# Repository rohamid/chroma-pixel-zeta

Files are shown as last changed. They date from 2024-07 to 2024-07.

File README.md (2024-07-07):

# TODO #
* Using IS42S16160 which is actually 32MB SDRAM, there must be 13 bit address (A0-A12). But I only populated 12-bit (A0-A11). Fix This
* Move the LCD FPC 40P slightly inside the PCB in order to match the actual LCD bend.
* Add VBUS control to the USB C in order to use USB Host capability
* I forgot to route 5V to 4P the JST-XH connector
* Rotate the ST-Link connector 180 degree to match the actual ST-Link connector bend

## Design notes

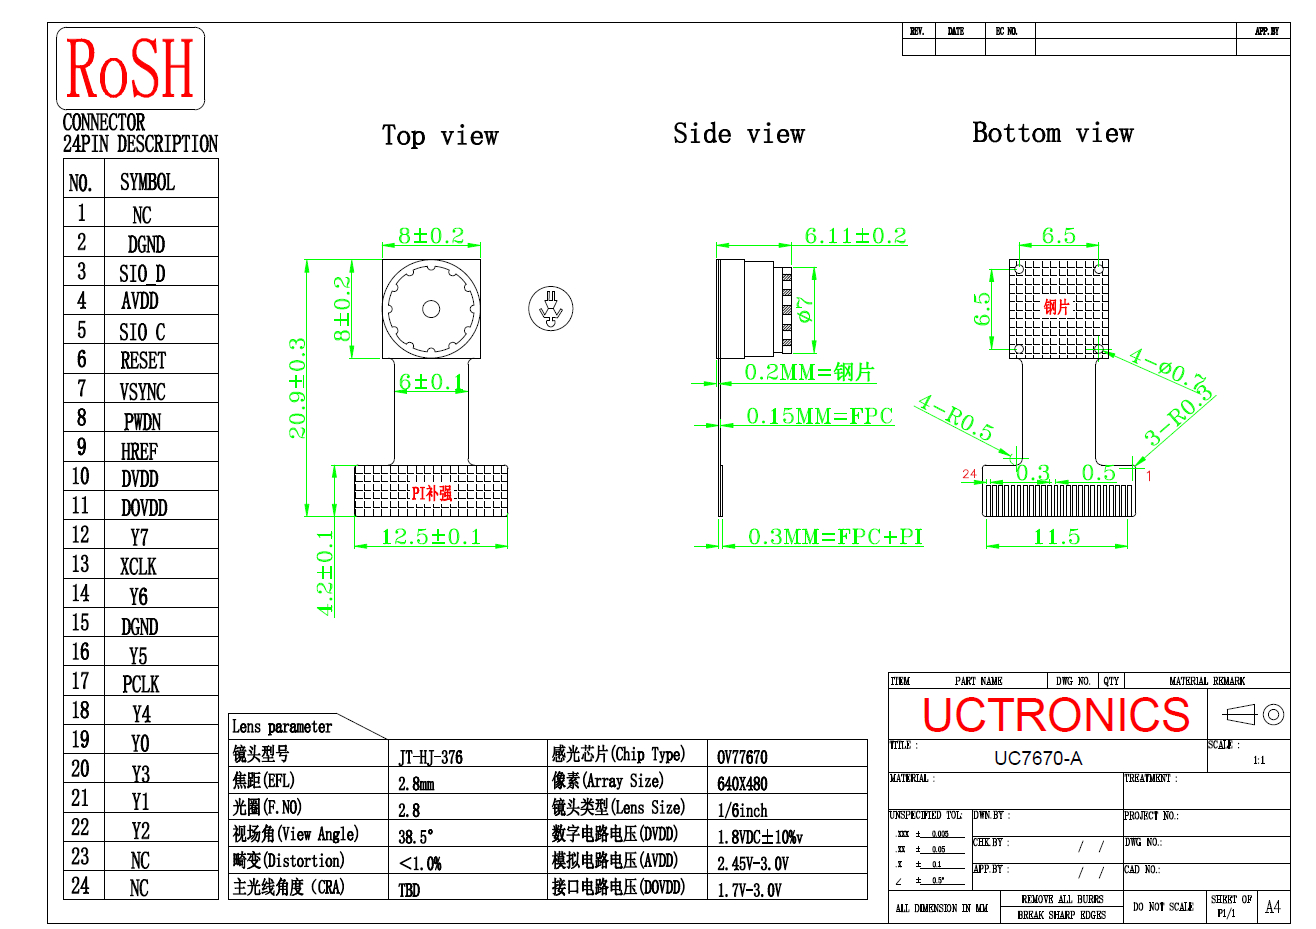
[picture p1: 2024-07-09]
doc/ezgif-5-22a7d3f66d.jpg

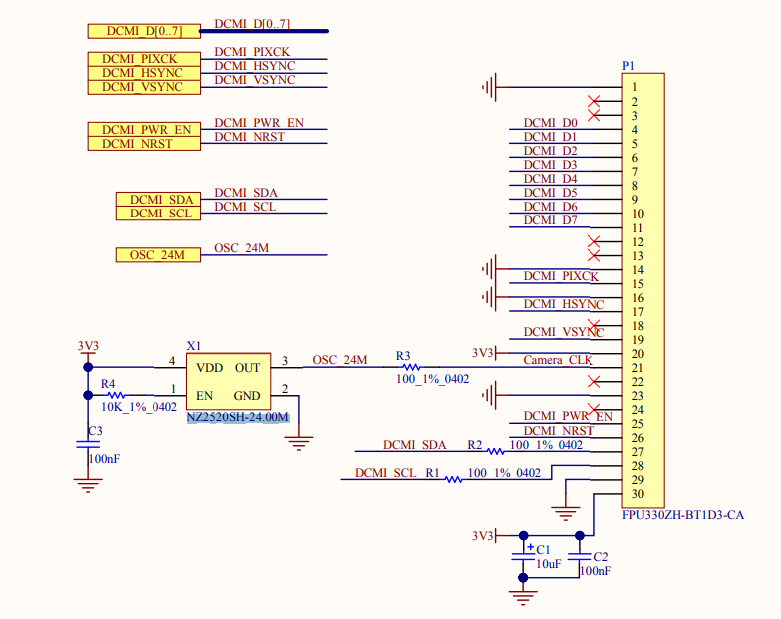
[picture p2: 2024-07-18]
camera-stm32.png

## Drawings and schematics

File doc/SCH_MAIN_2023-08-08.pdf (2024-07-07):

VDD 72 PB12 73 PB13 74 PB14 75 PB15 76 PD8 77 PD9 78 PD10 79 PD11 80 PD12 81 PD13 82 VSS 83 VDD 84 PD14 85 PD15 86 PG2 87 PG3 88 PG4 89 PG5 90 PG6 91 PG7 92 PG8 93 VSS 94 VDD33USB 95 PC6 96 PC7 97 PC8 98 PC9 99 PA8 100 PA9 101 PA10 102 PA11 103 PA12 104 PA13 105 VCAP 106 VSS 107 VDD 108 PA14 109 PA15 110 PC10 111 PC11 112 PC12 113 PD0 114 PD1 115 PD2 116 PD3 117 PD4 118 PD5 119 VSS 120 VDD 121 PD6 122 PD7 123 PG9 124 PG10 125 PG11 126 PG12 127 PG13 128 PG14 129 VSS 130 VDD 131 PG15 132 PB3 133 PB4 134 PB5 135 PB6 136 PB7 137 BOOT0 138 PB8 139 PB9 140 PE0 141 PE1 142 PDR_ON 143 VDD 144

# SDRAM

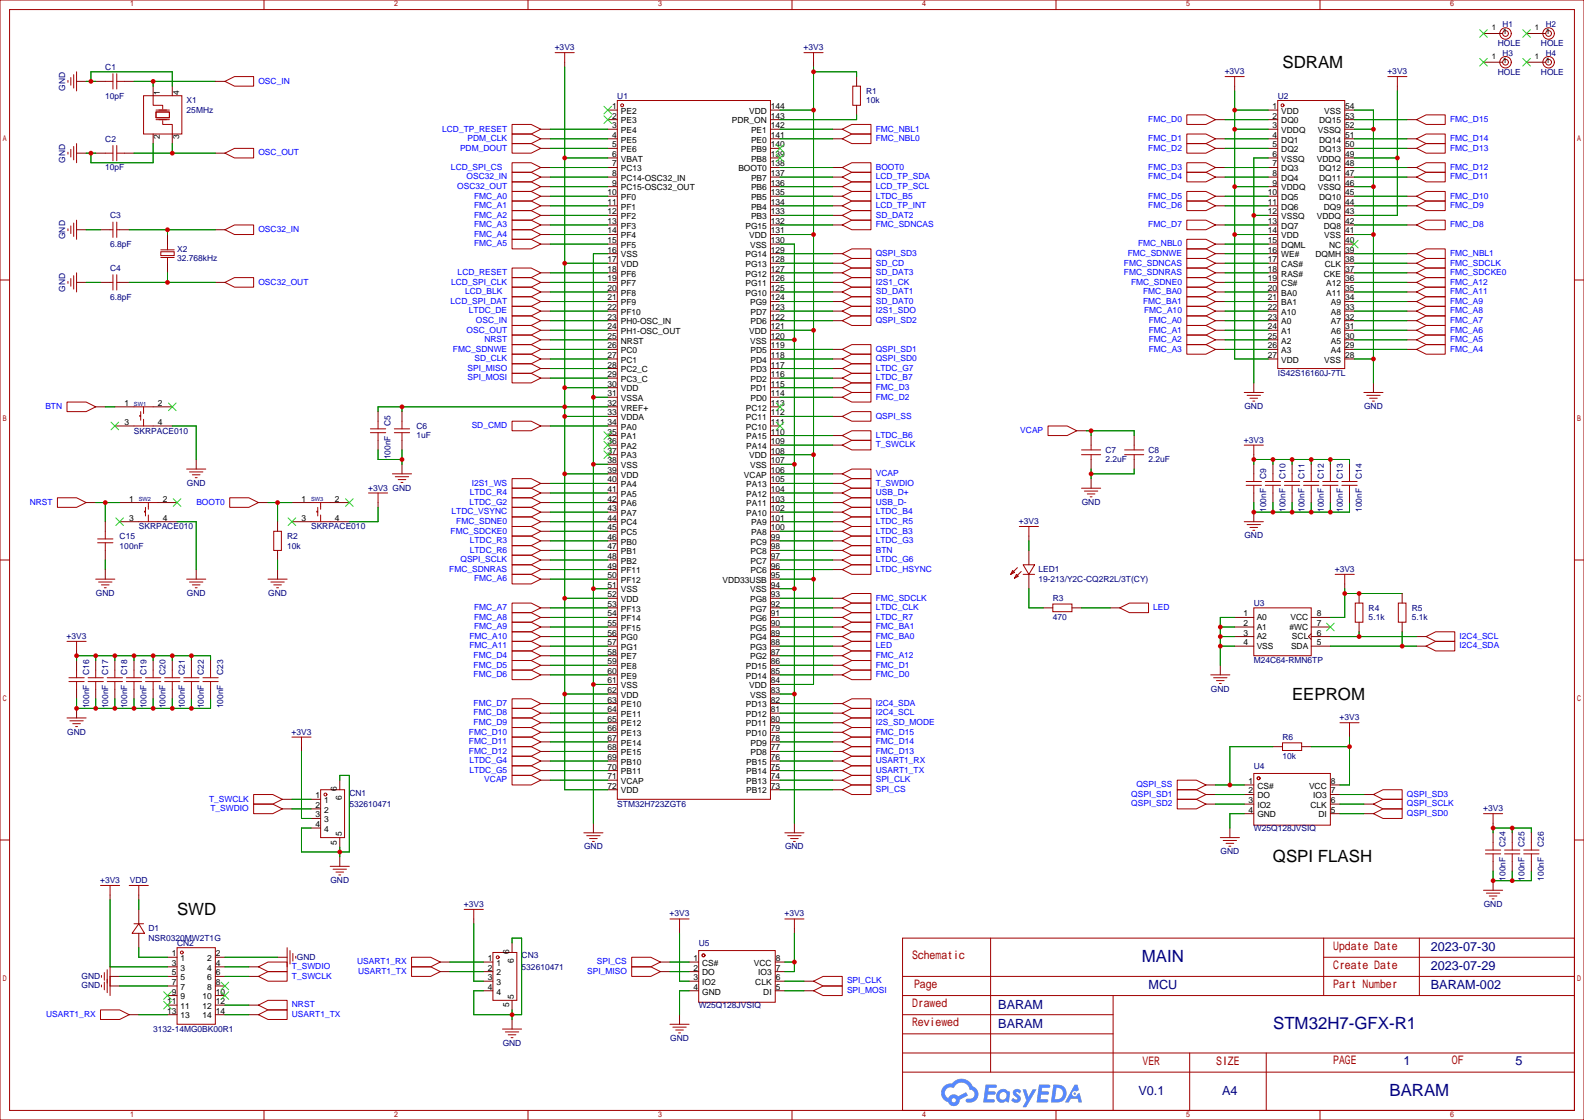
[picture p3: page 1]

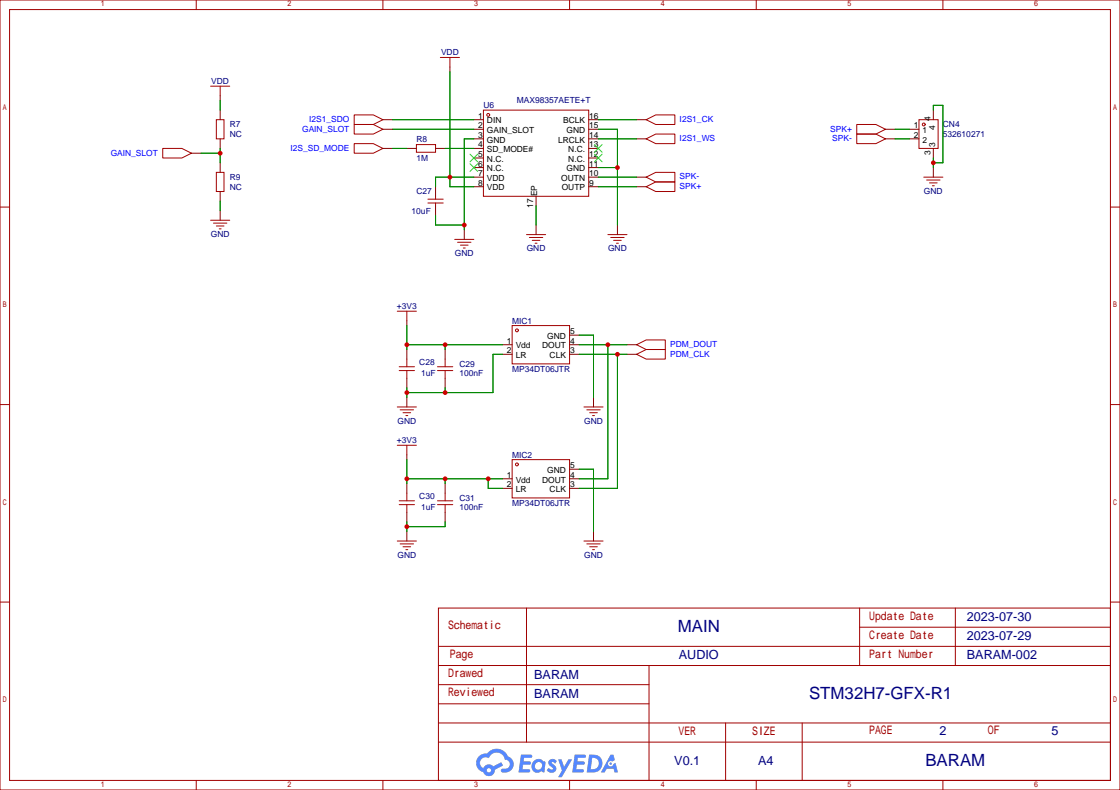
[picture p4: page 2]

OUTN 10 GND 11 N.C. 12 N.C. 13 LRCLK 14 GND 15 BCLK 16

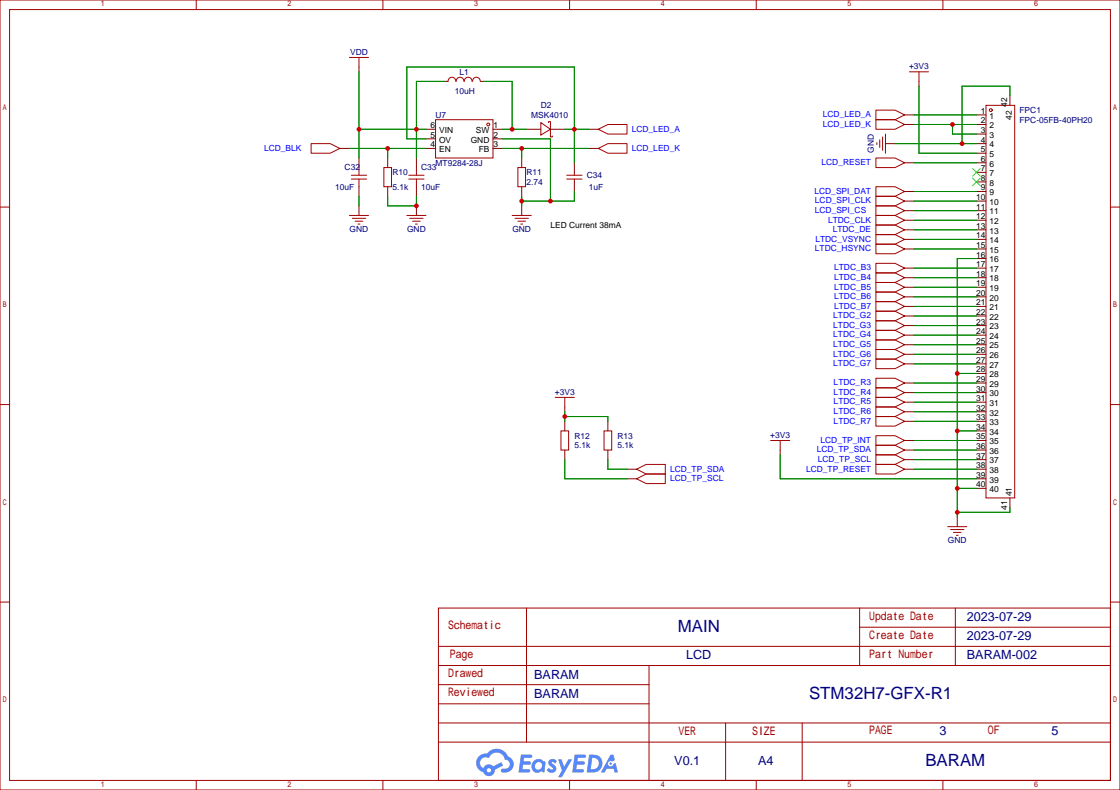
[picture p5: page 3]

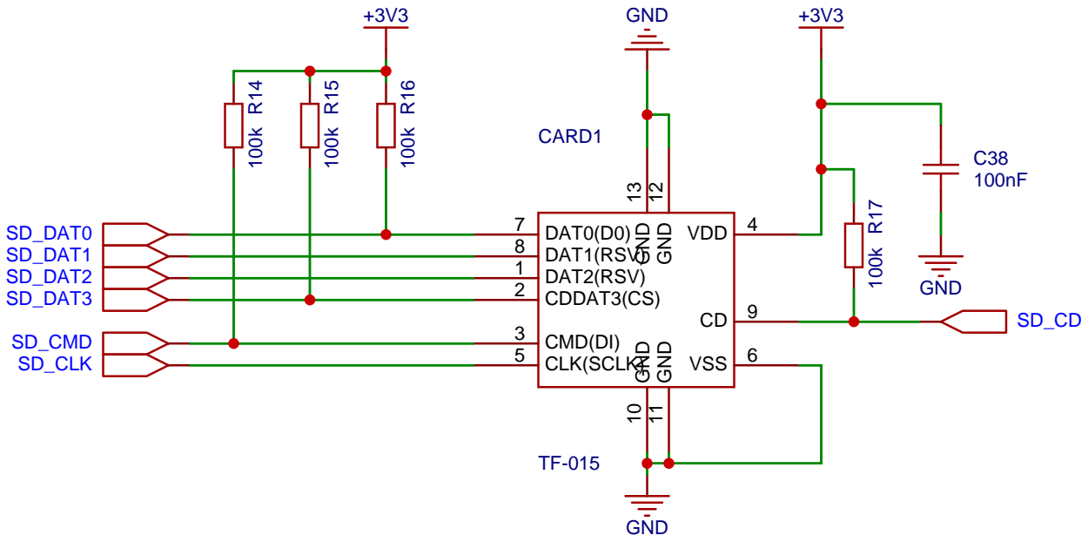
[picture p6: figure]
DAT2(RSV) 1 CDDAT3(CS) 2; CMD(DI) 3; VDD 4; CLK(SCLK) 5; VSS 6; DAT0(D0) 7; DAT1(RSV) 8; GND ¹³ GND 10; GND 11 GND 12; CARD1; GND; SD_DAT0 SD_DAT1 SD_DAT2 SD_DAT3; SD_CMD SD_CLK

Reviewed

Drawed

Create Date
Part Number

Schematic

Update Date

Page

## BARAM BARAM

# STM32H7-GFX-R1

2023-07-30

## 2023-07-29 MAIN

## BARAM-002

## SDCARD

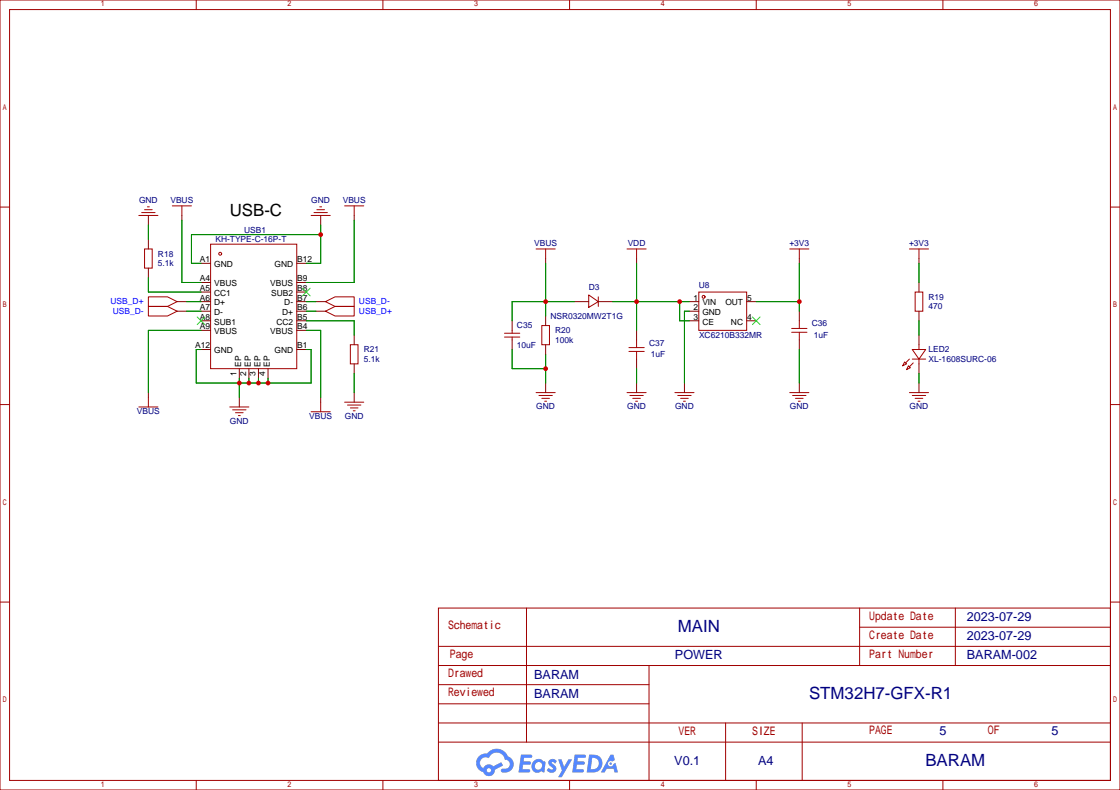
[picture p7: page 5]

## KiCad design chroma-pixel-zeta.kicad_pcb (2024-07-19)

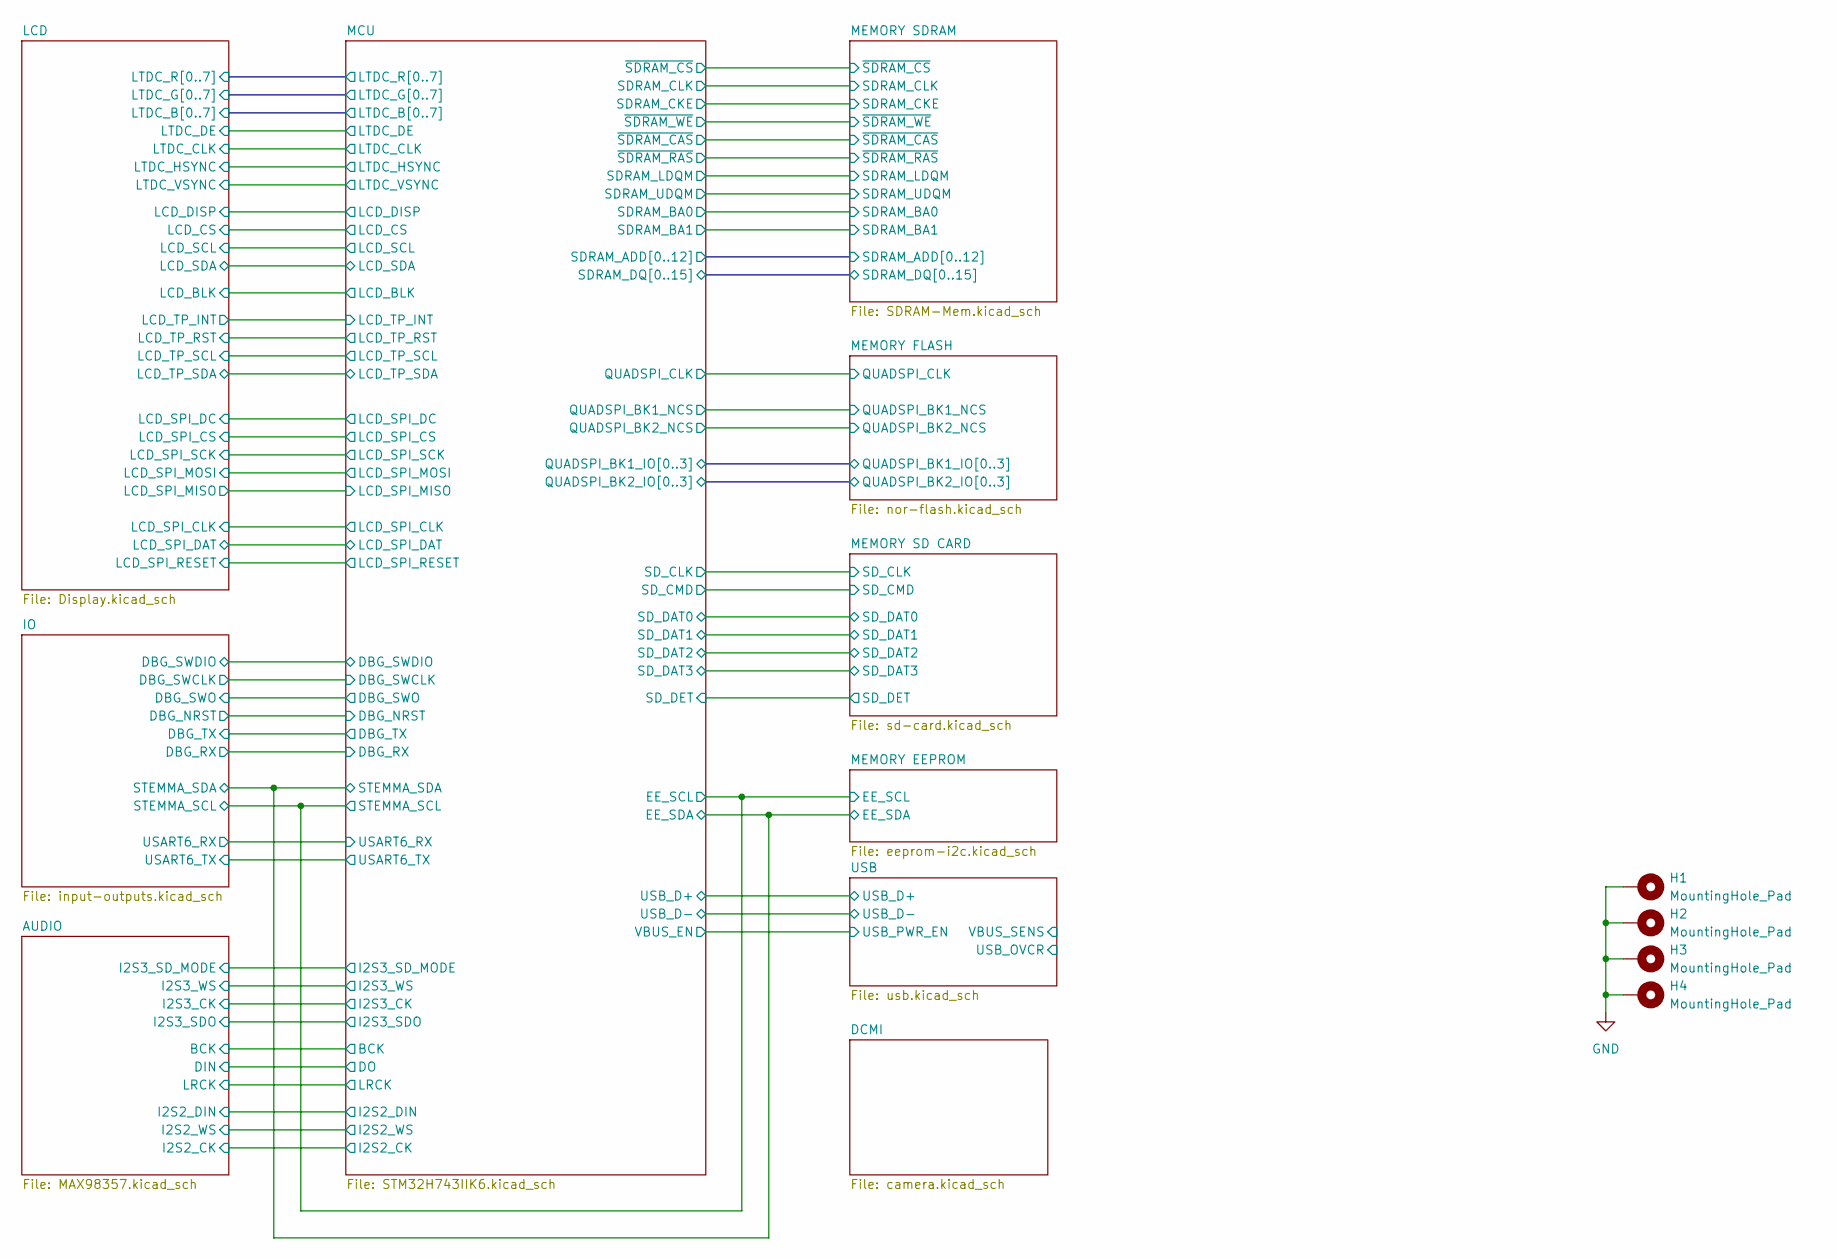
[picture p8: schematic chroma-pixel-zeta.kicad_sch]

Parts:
H1, H2, H3, H4: MountingHole_Pad; MountingHole_3.2mm_M3_Pad_Via

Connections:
GND: H1.1, H2.1, H3.1, H4.1; also elsewhere on the board

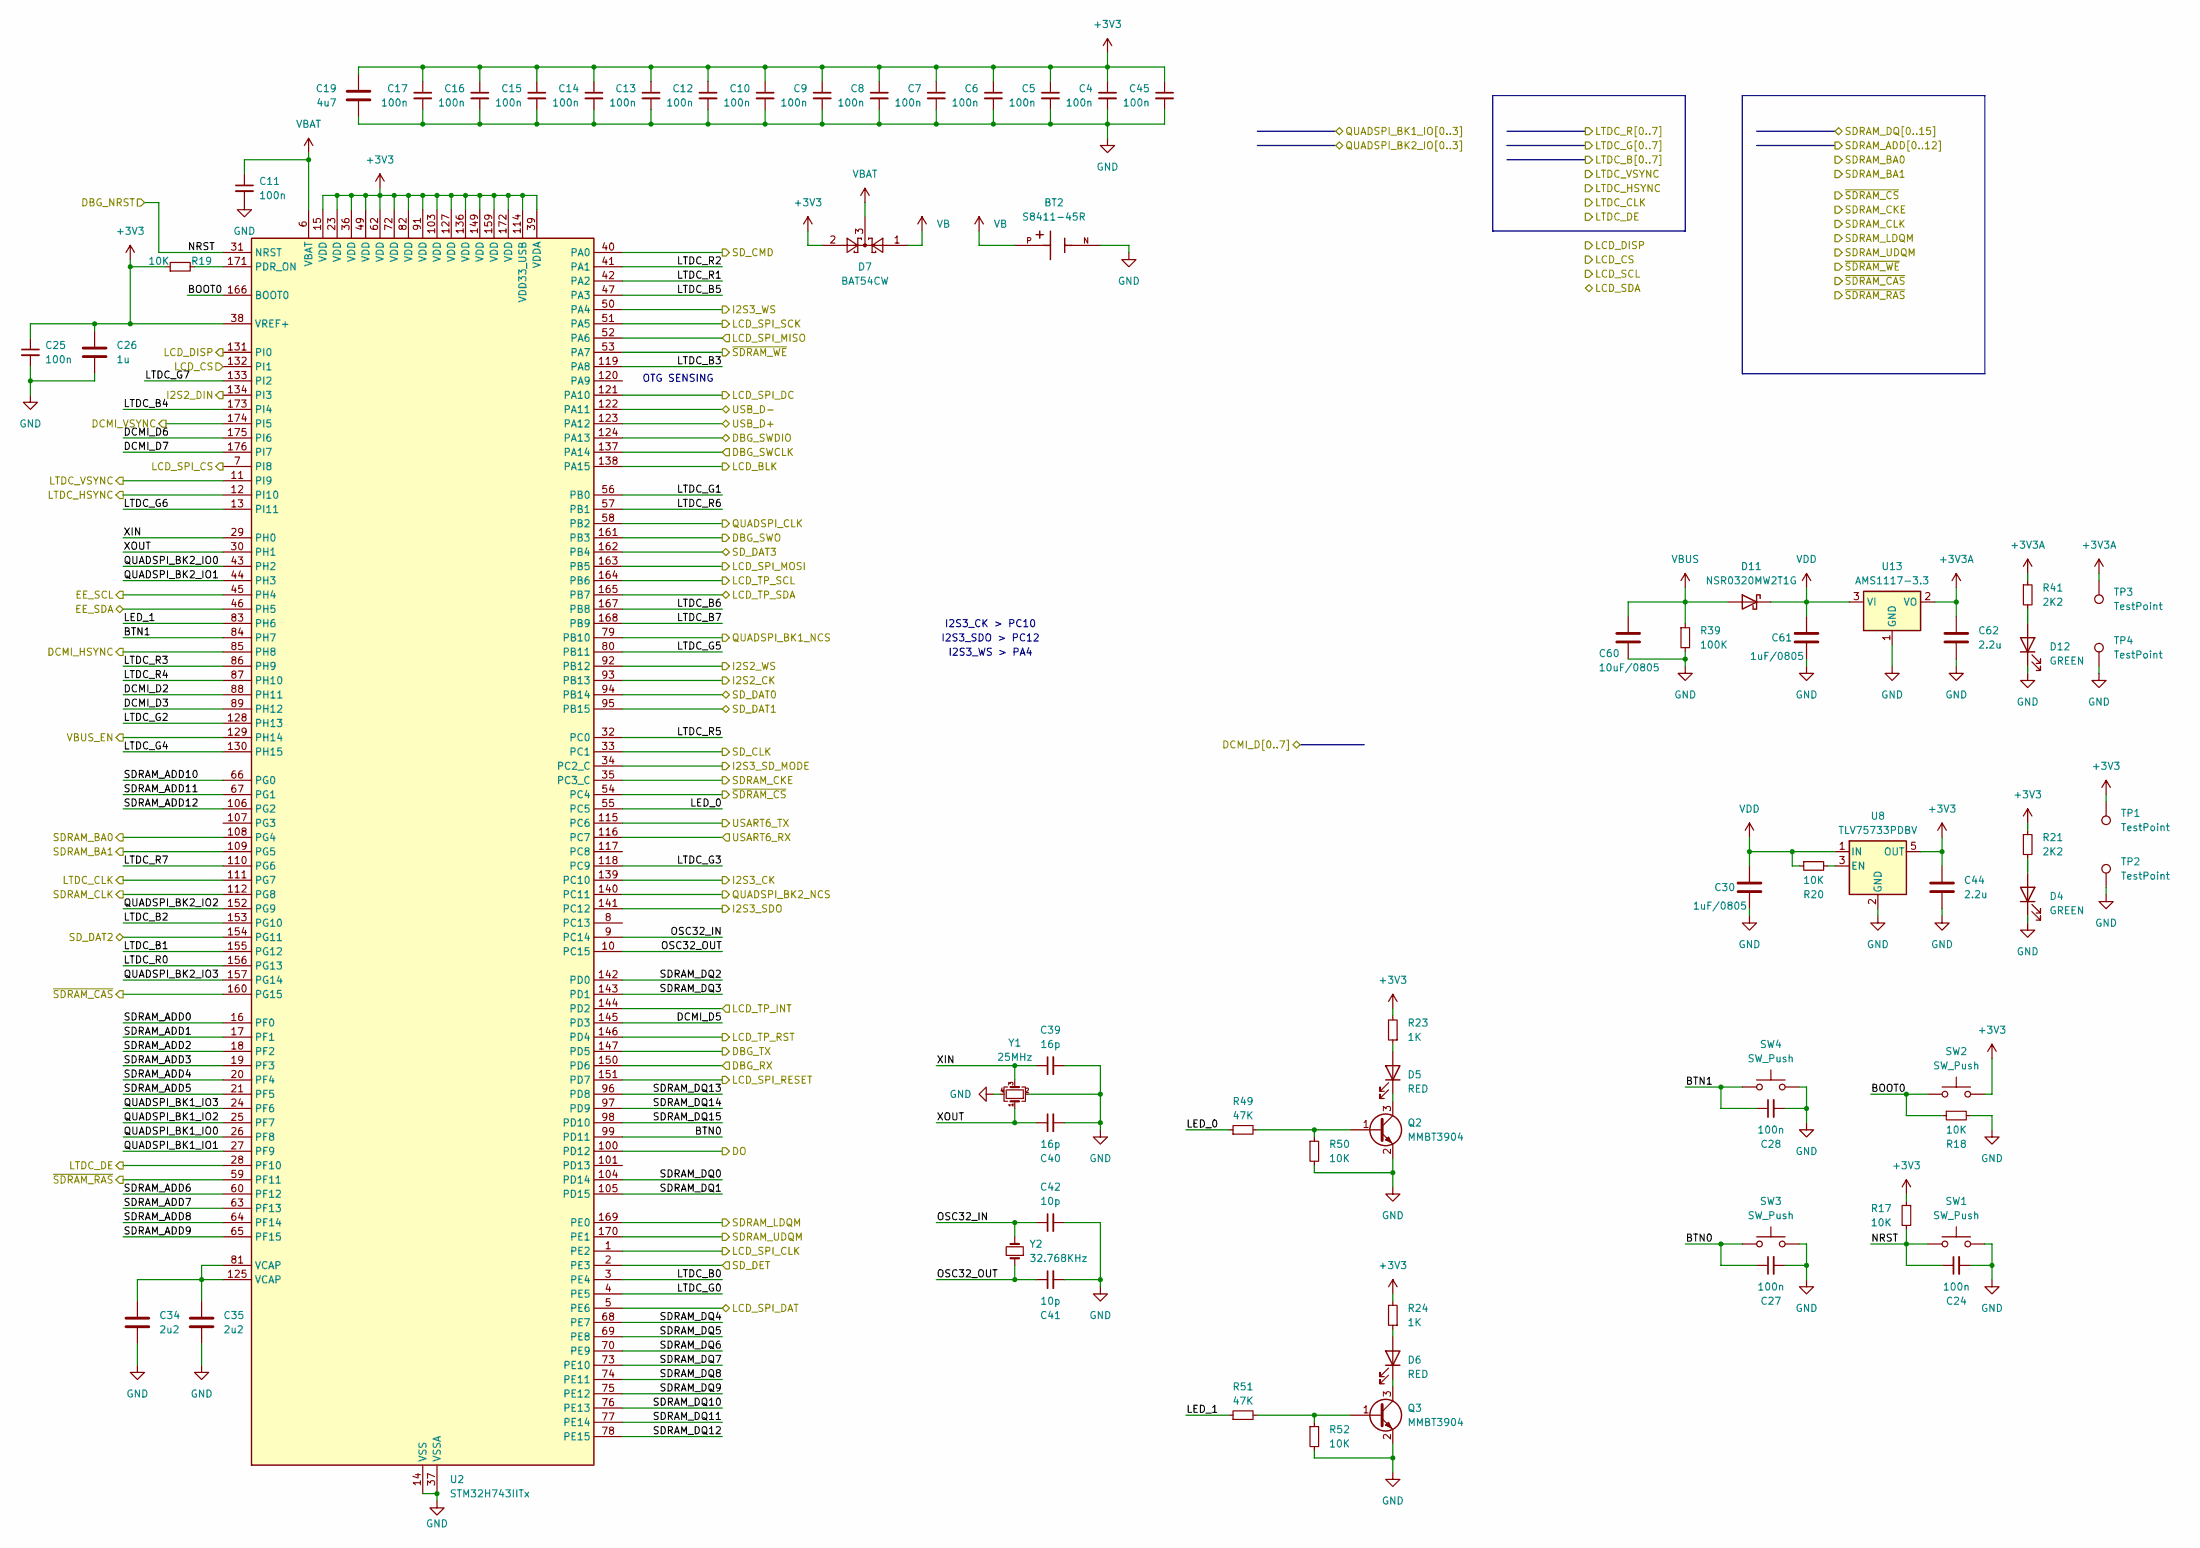
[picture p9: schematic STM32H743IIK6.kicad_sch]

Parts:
BT2: S8411-45R; CR1220-Batt-conn-S8411-45R; JLCPCB Part # C964729
C4, C5, C6, C7, C8, C9, C10, C11, C12, C13, C14, C15, C16, C17, C24, C25, C27, C28, C45: 100n; C_0402_1005Metric; JLCPCB Part # C307331
C19: 4u7; C_0603_1608Metric; JLCPCB Part # C19666
C26: 1u; C_0603_1608Metric; JLCPCB Part # C15849
C30, C61: 1uF/0805; C_0805_2012Metric; JLCPCB Part # C28323
C34, C35: 2u2; C_0603_1608Metric; JLCPCB Part # C23630
C39, C40: 16p; C_0402_1005Metric; JLCPCB Part # C77590
C41, C42: 10p; C_0402_1005Metric; JLCPCB Part # C32949
C44, C62: 2.2u; C_0805_2012Metric; JLCPCB Part # C377773
C60: 10uF/0805; C_0805_2012Metric; JLCPCB Part # C440198
D4, D12: GREEN; LED_0805_2012Metric; JLCPCB Part # C2297
D5, D6: RED; LED_0805_2012Metric; JLCPCB Part # C84256
D7: BAT54CW; SOT-23; JLCPCB Part # C37704
D11: NSR0320MW2T1G; D_SOD-323; JLCPCB Part # C48192
Q2, Q3: MMBT3904; SOT-23; JLCPCB Part # C20526
R17, R18, R19, R20, R50, R52: 10K; R_0402_1005Metric; JLCPCB Part # C25744
R21, R41: 2K2; R_0402_1005Metric; JLCPCB Part # C25879
R23, R24: 1K; R_0402_1005Metric; JLCPCB Part # C11702
R39: 100K; R_0402_1005Metric; JLCPCB Part # C60491
R49, R51: 47K; R_0402_1005Metric; JLCPCB Part # C25741
SW1, SW2, SW3, SW4: SW_Push; SW_SPST_PTS810; JLCPCB Part # C127488
TP1, TP2, TP3, TP4: TestPoint; TestPoint_Pad_D1.5mm
U2: STM32H743IITx; LQFP-176_24x24mm_P0.5mm; JLCPCB Part # C89597
U8: TLV75733PDBV; SOT-23-5; JLCPCB Part # C485517
U13: AMS1117-3.3; SOT-223-3_TabPin2; JLCPCB Part # C6186
Y1: 25MHz; Crystal_SMD_2520-4Pin_2.5x2.0mm; JLCPCB Part # C255954
Y2: 32.768KHz; Crystal_SMD_2012-2Pin_2.0x1.2mm; JLCPCB Part # C99009

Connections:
+3V3: C4.1, C5.1, C6.1, C7.1, C8.1, C9.1, C10.1, C12.1, C13.1, C14.1, C15.1, C16.1, C17.1, C19.1, C25.1, C26.1, C44.1, C45.1, D7.2, R17.1, R19.1, R21.1, R23.2, R24.2, SW2.2, TP1.1, U2.15 (VDD), U2.23 (VDD), U2.36 (VDD), U2.38 (VREF+), U2.39 (VDDA), U2.49 (VDD), U2.62 (VDD), U2.72 (VDD), U2.82 (VDD), U2.91 (VDD), U2.103 (VDD), U2.114 (VDD33_USB), U2.127 (VDD), U2.136 (VDD), U2.149 (VDD), U2.159 (VDD), U2.172 (VDD), U8.5 (OUT); also elsewhere on the board
+3V3A: C62.1, R41.1, TP3.1, U13.2 (VO); also elsewhere on the board
/AUDIO/I2S2_CK: U2.93 (PB13); also elsewhere on the board
/AUDIO/I2S2_DIN: U2.134 (PI3); also elsewhere on the board
/AUDIO/I2S2_WS: U2.92 (PB12); also elsewhere on the board
/AUDIO/I2S3_CK: U2.139 (PC10); also elsewhere on the board
/AUDIO/I2S3_SDO: U2.141 (PC12); also elsewhere on the board
/AUDIO/I2S3_SD_MODE: U2.34 (PC2_C); also elsewhere on the board
/AUDIO/I2S3_WS: U2.50 (PA4); also elsewhere on the board
/IO/DBG_RX: U2.150 (PD6); also elsewhere on the board
/IO/DBG_SWCLK: U2.137 (PA14); also elsewhere on the board
/IO/DBG_SWDIO: U2.124 (PA13); also elsewhere on the board
/IO/DBG_SWO: U2.161 (PB3); also elsewhere on the board
/IO/DBG_TX: U2.147 (PD5); also elsewhere on the board
/IO/STEMMA_SCL: U2.45 (PH4); also elsewhere on the board
/IO/STEMMA_SDA: U2.46 (PH5); also elsewhere on the board
/IO/USART6_RX: U2.116 (PC7); also elsewhere on the board
/IO/USART6_TX: U2.115 (PC6); also elsewhere on the board
/LCD/LCD_BLK: U2.138 (PA15); also elsewhere on the board
/LCD/LCD_CS: U2.132 (PI1); also elsewhere on the board
/LCD/LCD_DC: U2.121 (PA10); also elsewhere on the board
/LCD/LCD_DISP: U2.131 (PI0); also elsewhere on the board
/LCD/LCD_SCK: U2.51 (PA5); also elsewhere on the board
/LCD/LCD_SDI(MOSI): U2.163 (PB5); also elsewhere on the board
/LCD/LCD_SDO(MISO): U2.52 (PA6); also elsewhere on the board
/LCD/LCD_SPI_CLK: U2.1 (PE2); also elsewhere on the board
/LCD/LCD_SPI_CS: U2.7 (PI8); also elsewhere on the board
/LCD/LCD_SPI_DAT: U2.5 (PE6); also elsewhere on the board
/LCD/LCD_SPI_RESET: U2.151 (PD7); also elsewhere on the board
/LCD/LCD_TP_INT: U2.144 (PD2); also elsewhere on the board
/LCD/LCD_TP_RST: U2.146 (PD4); also elsewhere on the board
/LCD/LCD_TP_SCL: U2.164 (PB6); also elsewhere on the board
/LCD/LCD_TP_SDA: U2.165 (PB7); also elsewhere on the board
/LCD/LTDC_B0: U2.3 (PE4); also elsewhere on the board
/LCD/LTDC_B1: U2.155 (PG12); also elsewhere on the board
/LCD/LTDC_B2: U2.153 (PG10); also elsewhere on the board
/LCD/LTDC_B3: U2.119 (PA8); also elsewhere on the board
/LCD/LTDC_B4: U2.173 (PI4); also elsewhere on the board
/LCD/LTDC_B5: U2.47 (PA3); also elsewhere on the board
/LCD/LTDC_B6: U2.167 (PB8); also elsewhere on the board
/LCD/LTDC_B7: U2.168 (PB9); also elsewhere on the board
/LCD/LTDC_CLK: U2.111 (PG7); also elsewhere on the board
/LCD/LTDC_DE: U2.28 (PF10); also elsewhere on the board
/LCD/LTDC_G0: U2.4 (PE5); also elsewhere on the board
/LCD/LTDC_G1: U2.56 (PB0); also elsewhere on the board
/LCD/LTDC_G2: U2.128 (PH13); also elsewhere on the board
/LCD/LTDC_G3: U2.118 (PC9); also elsewhere on the board
/LCD/LTDC_G4: U2.130 (PH15); also elsewhere on the board
/LCD/LTDC_G5: U2.80 (PB11); also elsewhere on the board
/LCD/LTDC_G6: U2.13 (PI11); also elsewhere on the board
/LCD/LTDC_G7: U2.133 (PI2); also elsewhere on the board
/LCD/LTDC_HSYNC: U2.12 (PI10); also elsewhere on the board
/LCD/LTDC_R0: U2.156 (PG13); also elsewhere on the board
/LCD/LTDC_R1: U2.42 (PA2); also elsewhere on the board
/LCD/LTDC_R2: U2.41 (PA1); also elsewhere on the board
/LCD/LTDC_R3: U2.86 (PH9); also elsewhere on the board
/LCD/LTDC_R4: U2.87 (PH10); also elsewhere on the board
/LCD/LTDC_R5: U2.32 (PC0); also elsewhere on the board
/LCD/LTDC_R6: U2.57 (PB1); also elsewhere on the board
/LCD/LTDC_R7: U2.110 (PG6); also elsewhere on the board
/LCD/LTDC_VSYNC: U2.11 (PI9); also elsewhere on the board
/MCU/BOOT0: R18.1, SW2.1, U2.166 (BOOT0)
/MCU/BTN0: C27.1, SW3.1, U2.99 (PD11)
/MCU/BTN1: C28.1, SW4.1, U2.84 (PH7)
/MCU/DCMI_D2: U2.88 (PH11)
/MCU/DCMI_D3: U2.89 (PH12)
/MCU/DCMI_D5: U2.145 (PD3)
/MCU/DCMI_D6: U2.175 (PI6)
/MCU/DCMI_D7: U2.176 (PI7)
/MCU/DCMI_HSYNC: U2.85 (PH8)
/MCU/DCMI_VSYNC: U2.174 (PI5)
/MCU/DO: U2.100 (PD12)
/MCU/LED_0: R49.1, U2.55 (PC5)
/MCU/LED_1: R51.1, U2.83 (PH6)
/MCU/NRST: C24.1, R17.2, SW1.1, U2.31 (NRST); also elsewhere on the board
/MCU/OSC32_IN: C42.1, U2.9 (PC14), Y2.2
/MCU/OSC32_OUT: C41.1, U2.10 (PC15), Y2.1
/MCU/QUADSPI_BK1_IO0: U2.26 (PF8); also elsewhere on the board
/MCU/QUADSPI_BK1_IO1: U2.27 (PF9); also elsewhere on the board
/MCU/QUADSPI_BK1_IO2: U2.25 (PF7); also elsewhere on the board
/MCU/QUADSPI_BK1_IO3: U2.24 (PF6); also elsewhere on the board
/MCU/QUADSPI_BK1_NCS: U2.79 (PB10); also elsewhere on the board
/MCU/QUADSPI_BK2_IO0: U2.43 (PH2); also elsewhere on the board
/MCU/QUADSPI_BK2_IO1: U2.44 (PH3); also elsewhere on the board
/MCU/QUADSPI_BK2_IO2: U2.152 (PG9); also elsewhere on the board
/MCU/QUADSPI_BK2_IO3: U2.157 (PG14); also elsewhere on the board
/MCU/QUADSPI_BK2_NCS: U2.140 (PC11); also elsewhere on the board
/MCU/QUADSPI_CLK: U2.58 (PB2); also elsewhere on the board
/MCU/SDRAM_ADD0: U2.16 (PF0); also elsewhere on the board
/MCU/SDRAM_ADD1: U2.17 (PF1); also elsewhere on the board
/MCU/SDRAM_ADD2: U2.18 (PF2); also elsewhere on the board
/MCU/SDRAM_ADD3: U2.19 (PF3); also elsewhere on the board
/MCU/SDRAM_ADD4: U2.20 (PF4); also elsewhere on the board
/MCU/SDRAM_ADD5: U2.21 (PF5); also elsewhere on the board
/MCU/SDRAM_ADD6: U2.60 (PF12); also elsewhere on the board
/MCU/SDRAM_ADD7: U2.63 (PF13); also elsewhere on the board
/MCU/SDRAM_ADD8: U2.64 (PF14); also elsewhere on the board
/MCU/SDRAM_ADD9: U2.65 (PF15); also elsewhere on the board
/MCU/SDRAM_ADD10: U2.66 (PG0); also elsewhere on the board
/MCU/SDRAM_ADD11: U2.67 (PG1); also elsewhere on the board
/MCU/SDRAM_ADD12: U2.106 (PG2); also elsewhere on the board
/MCU/SDRAM_DQ0: U2.104 (PD14); also elsewhere on the board
/MCU/SDRAM_DQ1: U2.105 (PD15); also elsewhere on the board
/MCU/SDRAM_DQ2: U2.142 (PD0); also elsewhere on the board
/MCU/SDRAM_DQ3: U2.143 (PD1); also elsewhere on the board
/MCU/SDRAM_DQ4: U2.68 (PE7); also elsewhere on the board
/MCU/SDRAM_DQ5: U2.69 (PE8); also elsewhere on the board
/MCU/SDRAM_DQ6: U2.70 (PE9); also elsewhere on the board
/MCU/SDRAM_DQ7: U2.73 (PE10); also elsewhere on the board
/MCU/SDRAM_DQ8: U2.74 (PE11); also elsewhere on the board
/MCU/SDRAM_DQ9: U2.75 (PE12); also elsewhere on the board
/MCU/SDRAM_DQ10: U2.76 (PE13); also elsewhere on the board
/MCU/SDRAM_DQ11: U2.77 (PE14); also elsewhere on the board
/MCU/SDRAM_DQ12: U2.78 (PE15); also elsewhere on the board
/MCU/SDRAM_DQ13: U2.96 (PD8); also elsewhere on the board
/MCU/SDRAM_DQ14: U2.97 (PD9); also elsewhere on the board
/MCU/SDRAM_DQ15: U2.98 (PD10); also elsewhere on the board
/MCU/SD_CLK: U2.33 (PC1); also elsewhere on the board
/MCU/SD_CMD: U2.40 (PA0); also elsewhere on the board
/MCU/SD_DAT0: U2.94 (PB14); also elsewhere on the board
/MCU/SD_DAT1: U2.95 (PB15); also elsewhere on the board
/MCU/SD_DAT2: U2.154 (PG11); also elsewhere on the board
/MCU/SD_DAT3: U2.162 (PB4); also elsewhere on the board
/MCU/SD_DET: U2.2 (PE3); also elsewhere on the board
/MCU/VBUS_EN: U2.129 (PH14); also elsewhere on the board
/MCU/XIN: C39.1, U2.29 (PH0), Y1.3
/MCU/XOUT: C40.1, U2.30 (PH1), Y1.1
/MEMORY SDRAM/SDRAM_BA0: U2.108 (PG4); also elsewhere on the board
/MEMORY SDRAM/SDRAM_BA1: U2.109 (PG5); also elsewhere on the board
/MEMORY SDRAM/SDRAM_CKE: U2.35 (PC3_C); also elsewhere on the board
/MEMORY SDRAM/SDRAM_CLK: U2.112 (PG8); also elsewhere on the board
/MEMORY SDRAM/SDRAM_LDQM: U2.169 (PE0); also elsewhere on the board
/MEMORY SDRAM/SDRAM_UDQM: U2.170 (PE1); also elsewhere on the board
/MEMORY SDRAM/~SDRAM_CAS: U2.160 (PG15); also elsewhere on the board
/MEMORY SDRAM/~SDRAM_CS: U2.54 (PC4); also elsewhere on the board
/MEMORY SDRAM/~SDRAM_RAS: U2.59 (PF11); also elsewhere on the board
/MEMORY SDRAM/~SDRAM_WE: U2.53 (PA7); also elsewhere on the board
/USB/USB_D+: U2.123 (PA12); also elsewhere on the board
/USB/USB_D-: U2.122 (PA11); also elsewhere on the board
GND: BT2.N, C4.2, C5.2, C6.2, C7.2, C8.2, C9.2, C10.2, C11.2, C12.2, C13.2, C14.2, C15.2, C16.2, C17.2, C19.2, C24.2, C25.2, C26.2, C27.2, C28.2, C30.2, C34.2, C35.2, C39.2, C40.2, C41.2, C42.2, C44.2, C45.2, C60.2, C61.2, C62.2, D4.1 (K), D12.1 (K), Q2.2 (E), Q3.2 (E), R18.2, R39.2, R50.2, R52.2, SW1.2, SW3.2, SW4.2, TP2.1, TP4.1, U2.14 (VSS), U2.22 (VSS), U2.37 (VSSA), U2.48 (VSS), U2.61 (VSS), U2.71 (VSS), U2.90 (VSS), U2.102 (VSS), U2.113 (VSS), U2.126 (VSS), U2.135 (VSS), U2.148 (VSS), U2.158 (VSS), U8.2 (GND), U13.1 (GND), Y1.2, Y1.4; also elsewhere on the board
unnamed: C34.1, C35.1, U2.81 (VCAP), U2.125 (VCAP)
unnamed: D4.2 (A), R21.2
unnamed: D5.2 (A), R23.1
unnamed: D5.1 (K), Q2.3 (C)
unnamed: D6.2 (A), R24.1
unnamed: D6.1 (K), Q3.3 (C)
unnamed: D12.2 (A), R41.2
unnamed: Q2.1 (B), R49.2, R50.1
unnamed: Q3.1 (B), R51.2, R52.1
unnamed: R19.2, U2.171 (PDR_ON)
unnamed: R20.2, U8.3 (EN)
VB: BT2.P, D7.1
VBAT: C11.1, D7.3, U2.6 (VBAT)
VBUS: C60.1, D11.2 (A), R39.1; also elsewhere on the board
VDD: C30.1, C61.1, D11.1 (K), R20.1, U8.1 (IN), U13.3 (VI); also elsewhere on the board

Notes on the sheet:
I2S3_WS > PA4
I2S3_SDO > PC12
I2S3_CK > PC10
OTG SENSING

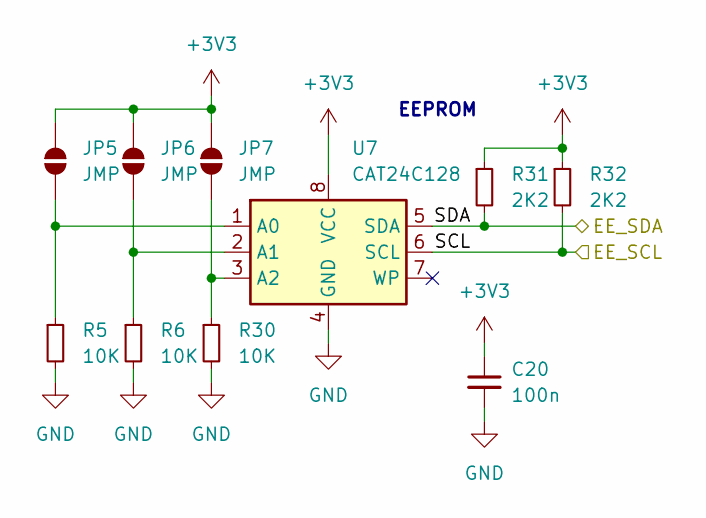
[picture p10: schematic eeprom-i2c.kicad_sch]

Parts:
C20: 100n; C_0402_1005Metric; JLCPCB Part # C307331
JP5, JP6, JP7: JMP; SolderJumper-2_P1.3mm_Open_RoundedPad1.0x1.5mm
R5, R6, R30: 10K; R_0402_1005Metric; JLCPCB Part # C25744
R31, R32: 2K2; R_0402_1005Metric; JLCPCB Part # C25879
U7: CAT24C128; SOIC-8_3.9x4.9mm_P1.27mm; JLCPCB Part # C6482

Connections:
+3V3: C20.1, JP5.2 (B), JP6.2 (B), JP7.2 (B), R31.1, R32.1, U7.8 (VCC); also elsewhere on the board
/IO/STEMMA_SCL: R32.2, U7.6 (SCL); also elsewhere on the board
/IO/STEMMA_SDA: R31.2, U7.5 (SDA); also elsewhere on the board
GND: C20.2, R5.2, R6.2, R30.2, U7.4 (GND); also elsewhere on the board
unnamed: JP5.1 (A), R5.1, U7.1 (A0)
unnamed: JP6.1 (A), R6.1, U7.2 (A1)
unnamed: JP7.1 (A), R30.1, U7.3 (A2)

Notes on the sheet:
EEPROM

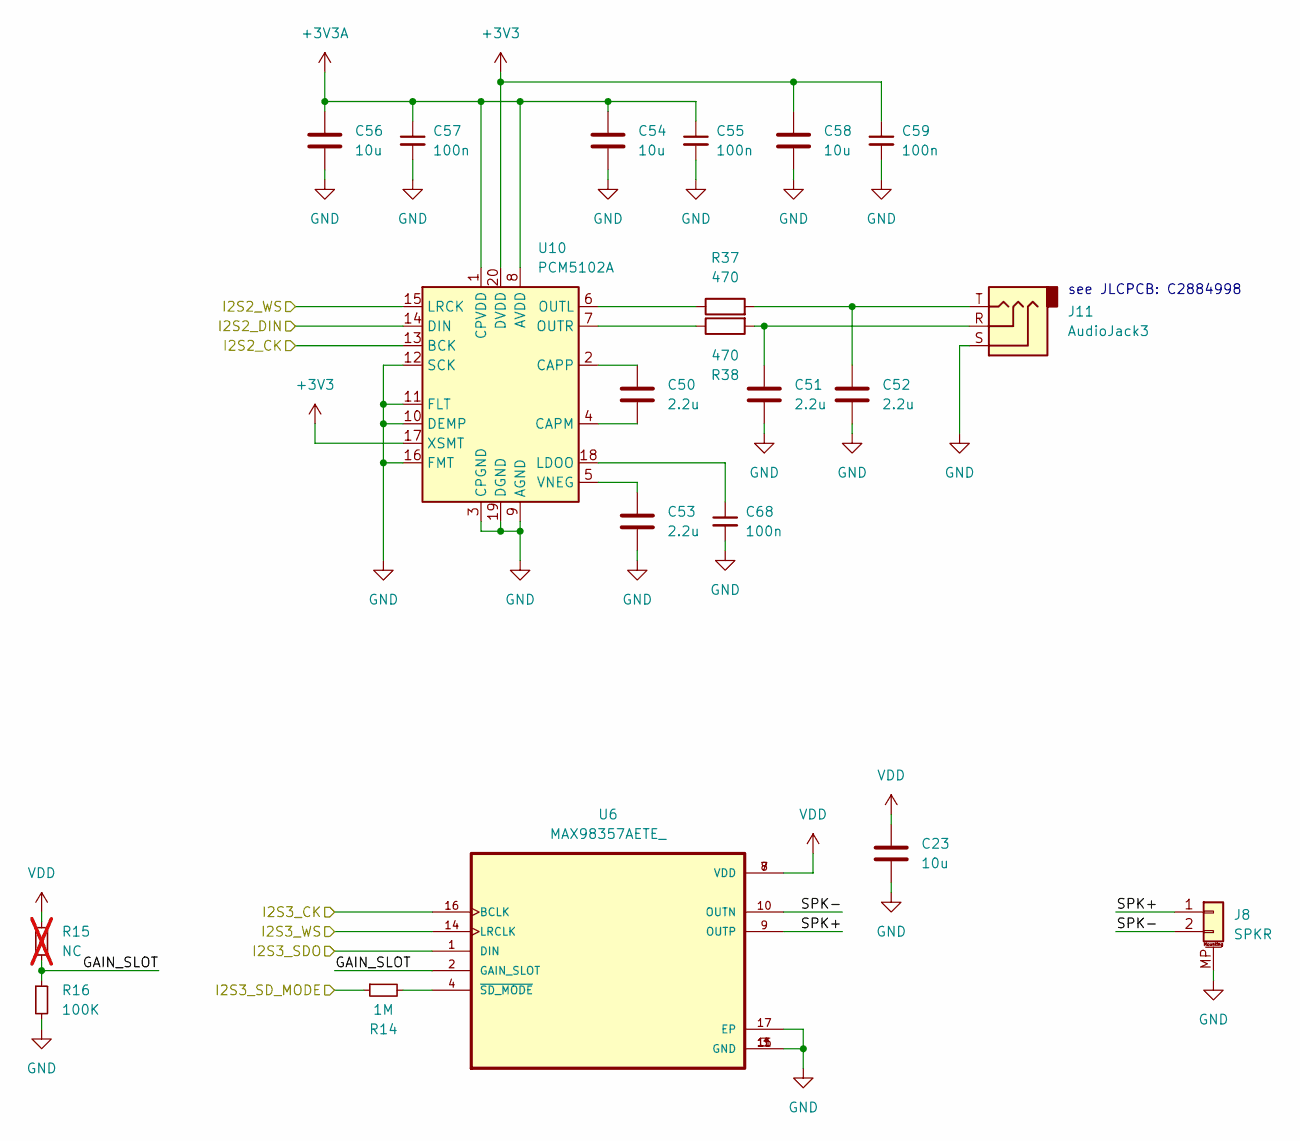
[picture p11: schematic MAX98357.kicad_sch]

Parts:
C23, C54, C56, C58: 10u; C_0603_1608Metric; JLCPCB Part # C96446
C50, C51, C52, C53: 2.2u; C_0805_2012Metric; JLCPCB Part # C377773
C55, C57, C59, C68: 100n; C_0402_1005Metric; JLCPCB Part # C307331
J8: SPKR; Hirose_DF13C_CL535-0402-2-51_1x02-1MP_P1.25mm_Vertical; JLCPCB Part # C7419891
J11: AudioJack3; XKB-PJ-320B-SMT; JLCPCB Part # C2884998
R14: 1M; R_0402_1005Metric; JLCPCB Part # C26083
R15: NC; R_0402_1005Metric; not fitted
R16: 100K; R_0402_1005Metric; JLCPCB Part # C60491
R37, R38: 470; R_0603_1608Metric; JLCPCB Part # C23179
U6: MAX98357AETE_; QFN50P300X300X80-17N; JLCPCB Part # C910544
U10: PCM5102A; TSSOP-20_4.4x6.5mm_P0.65mm; JLCPCB Part # C107671

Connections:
+3V3: C58.1, C59.1, U10.17 (XSMT), U10.20 (DVDD); also elsewhere on the board
+3V3A: C54.1, C55.1, C56.1, C57.1, U10.1 (CPVDD), U10.8 (AVDD); also elsewhere on the board
/AUDIO/GAIN_SLOT: R15.2, R16.1, U6.2 (GAIN_SLOT)
/AUDIO/I2S2_CK: U10.13 (BCK); also elsewhere on the board
/AUDIO/I2S2_DIN: U10.14 (DIN); also elsewhere on the board
/AUDIO/I2S2_WS: U10.15 (LRCK); also elsewhere on the board
/AUDIO/I2S3_CK: U6.16 (BCLK); also elsewhere on the board
/AUDIO/I2S3_SDO: U6.1 (DIN); also elsewhere on the board
/AUDIO/I2S3_SD_MODE: R14.1; also elsewhere on the board
/AUDIO/I2S3_WS: U6.14 (LRCLK); also elsewhere on the board
/AUDIO/SPK+: J8.1, U6.9 (OUTP)
/AUDIO/SPK-: J8.2, U6.10 (OUTN)
GND: C23.2, C51.2, C52.2, C53.2, C54.2, C55.2, C56.2, C57.2, C58.2, C59.2, C68.2, J8.MP (MountPin), J11.S, R16.2, U6.3 (GND), U6.11 (GND), U6.15 (GND), U6.17 (EP), U10.3 (CPGND), U10.9 (AGND), U10.10 (DEMP), U10.11 (FLT), U10.12 (SCK), U10.16 (FMT), U10.19 (DGND); also elsewhere on the board
unnamed: C51.1, J11.R, R38.2
unnamed: C52.1, J11.T, R37.2
unnamed: R14.2, U6.4 (~SD_MODE)
unnamed: C50.2, U10.4 (CAPM)
unnamed: C50.1, U10.2 (CAPP)
unnamed: C68.1, U10.18 (LDOO)
unnamed: R37.1, U10.6 (OUTL)
unnamed: R38.1, U10.7 (OUTR)
unnamed: C53.1, U10.5 (VNEG)
VDD: C23.1, R15.1, U6.7 (VDD), U6.8 (VDD); also elsewhere on the board

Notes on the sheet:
see JLCPCB: C2884998

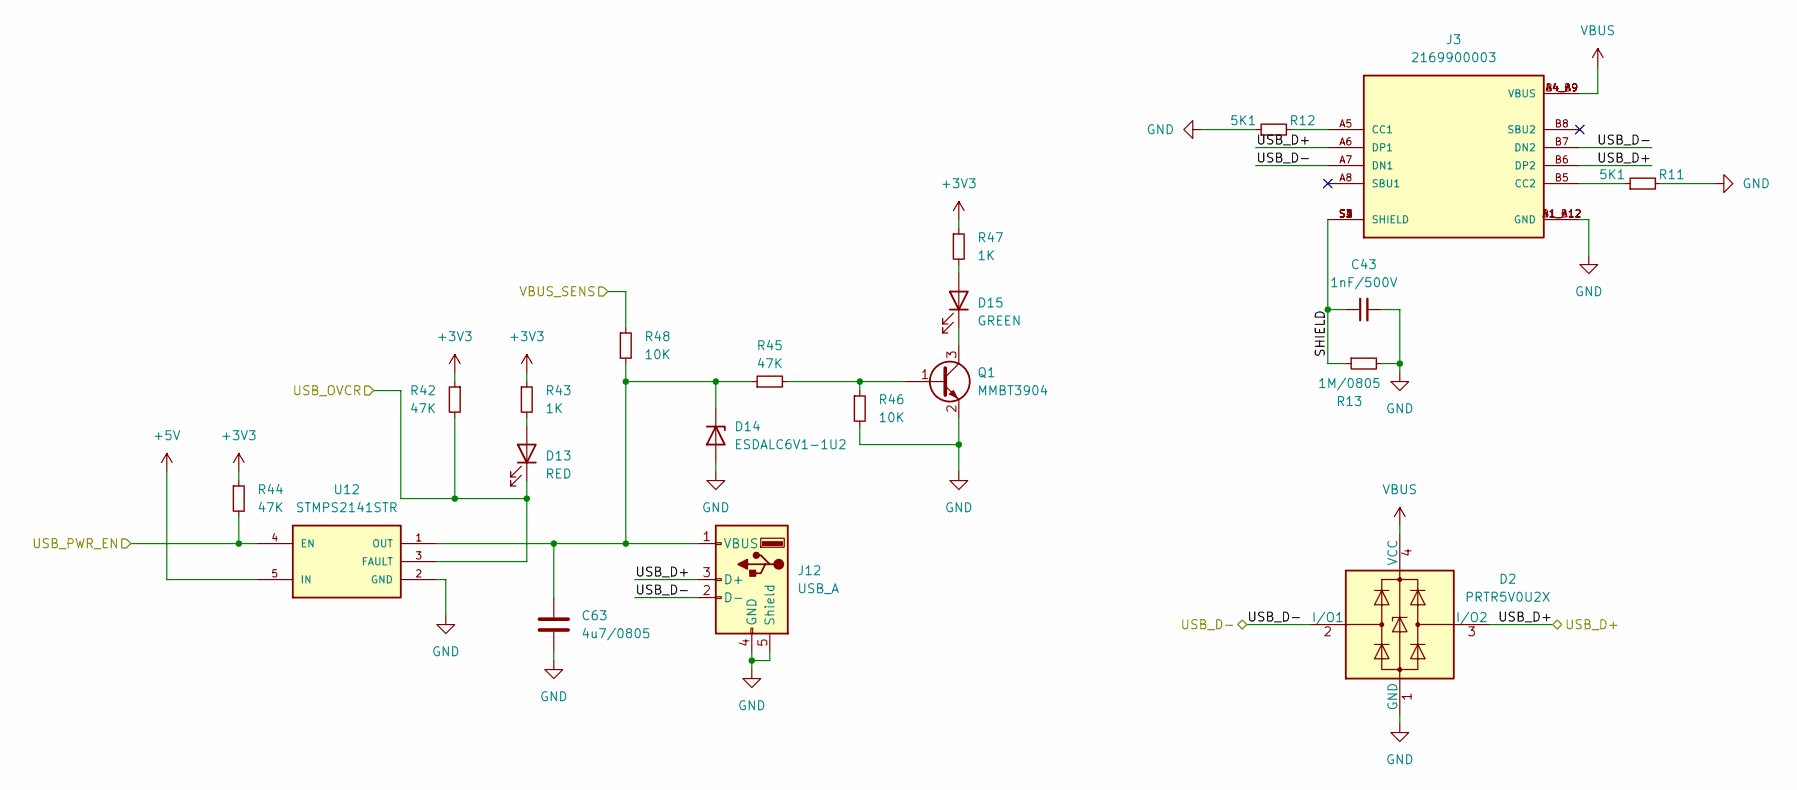
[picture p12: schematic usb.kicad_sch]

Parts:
C43: 1nF/500V; C_1206_3216Metric; JLCPCB Part # C35216
C63: 4u7/0805; C_0805_2012Metric; JLCPCB Part # C98192
D2: PRTR5V0U2X; SOT-143; JLCPCB Part # C12333
D13: RED; LED_0805_2012Metric; JLCPCB Part # C84256
D14: ESDALC6V1-1U2; D_SOD-523; JLCPCB Part # C1974498
D15: GREEN; LED_0805_2012Metric; JLCPCB Part # C2297
J3: 2169900003; USB_C_Mid_mount_MOLEX_2169900003; PARTREV A1
J12: USB_A; USB_A_Molex_67643_Horizontal
Q1: MMBT3904; SOT-23; JLCPCB Part # C20526
R11, R12: 5K1; R_0402_1005Metric; JLCPCB Part # C25905
R13: 1M/0805; R_0805_2012Metric; JLCPCB Part # C17514
R42, R44, R45: 47K; R_0402_1005Metric; JLCPCB Part # C25741
R43, R47: 1K; R_0402_1005Metric; JLCPCB Part # C11702
R46, R48: 10K; R_0402_1005Metric; JLCPCB Part # C25744
U12: STMPS2141STR; SOT95P280X145-5N; JLCPCB Part # C54624

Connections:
+3V3: R42.1, R43.1, R44.1, R47.1; also elsewhere on the board
+5V: U12.5 (IN); also elsewhere on the board
/MCU/VBUS_EN: R44.2, U12.4 (EN); also elsewhere on the board
/USB/SHIELD: C43.1, J3.S1 (SHIELD), J3.S2 (SHIELD), J3.S3 (SHIELD), J3.S4 (SHIELD), R13.1
/USB/USB_D+: D2.3 (I/O2), J3.A6 (DP1), J3.B6 (DP2), J12.3 (D+); also elsewhere on the board
/USB/USB_D-: D2.2 (I/O1), J3.A7 (DN1), J3.B7 (DN2), J12.2 (D-); also elsewhere on the board
/USB/USB_OVCR: D13.1 (K), R42.2, U12.3 (FAULT)
/USB/VBUS_SENS: R48.1
GND: C43.2, C63.2, D2.1 (GND), D14.2 (A), J3.A1_B12 (GND), J3.B1_A12 (GND), J12.4 (GND), J12.5 (Shield), Q1.2 (E), R11.2, R12.1, R13.2, R46.2, U12.2 (GND); also elsewhere on the board
unnamed: D13.2 (A), R43.2
unnamed: C63.1, D14.1 (K), J12.1 (VBUS), R45.1, R48.2, U12.1 (OUT)
unnamed: D15.2 (A), R47.2
unnamed: D15.1 (K), Q1.3 (C)
unnamed: J3.A5 (CC1), R12.2
unnamed: J3.B5 (CC2), R11.1
unnamed: Q1.1 (B), R45.2, R46.1
VBUS: D2.4 (VCC), J3.A4_B9 (VBUS), J3.B4_A9 (VBUS); also elsewhere on the board

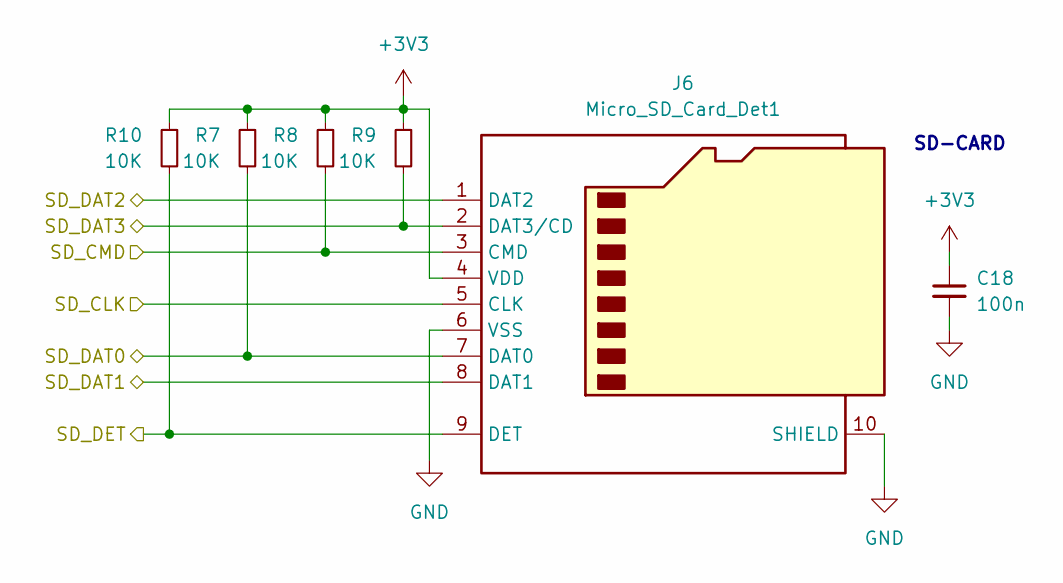
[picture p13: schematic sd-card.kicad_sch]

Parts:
C18: 100n; C_0402_1005Metric; JLCPCB Part # C307331
J6: Micro_SD_Card_Det1; SD-TF-115; JLCPCB Part # C266621
R7, R8, R9, R10: 10K; R_0402_1005Metric; JLCPCB Part # C25744

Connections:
+3V3: C18.1, J6.4 (VDD), R7.1, R8.1, R9.1, R10.1; also elsewhere on the board
/MCU/SD_CLK: J6.5 (CLK); also elsewhere on the board
/MCU/SD_CMD: J6.3 (CMD), R8.2; also elsewhere on the board
/MCU/SD_DAT0: J6.7 (DAT0), R7.2; also elsewhere on the board
/MCU/SD_DAT1: J6.8 (DAT1); also elsewhere on the board
/MCU/SD_DAT2: J6.1 (DAT2); also elsewhere on the board
/MCU/SD_DAT3: J6.2 (DAT3/CD), R9.2; also elsewhere on the board
/MCU/SD_DET: J6.9 (DET), R10.2; also elsewhere on the board
GND: C18.2, J6.6 (VSS), J6.10 (SHIELD); also elsewhere on the board

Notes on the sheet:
SD-CARD

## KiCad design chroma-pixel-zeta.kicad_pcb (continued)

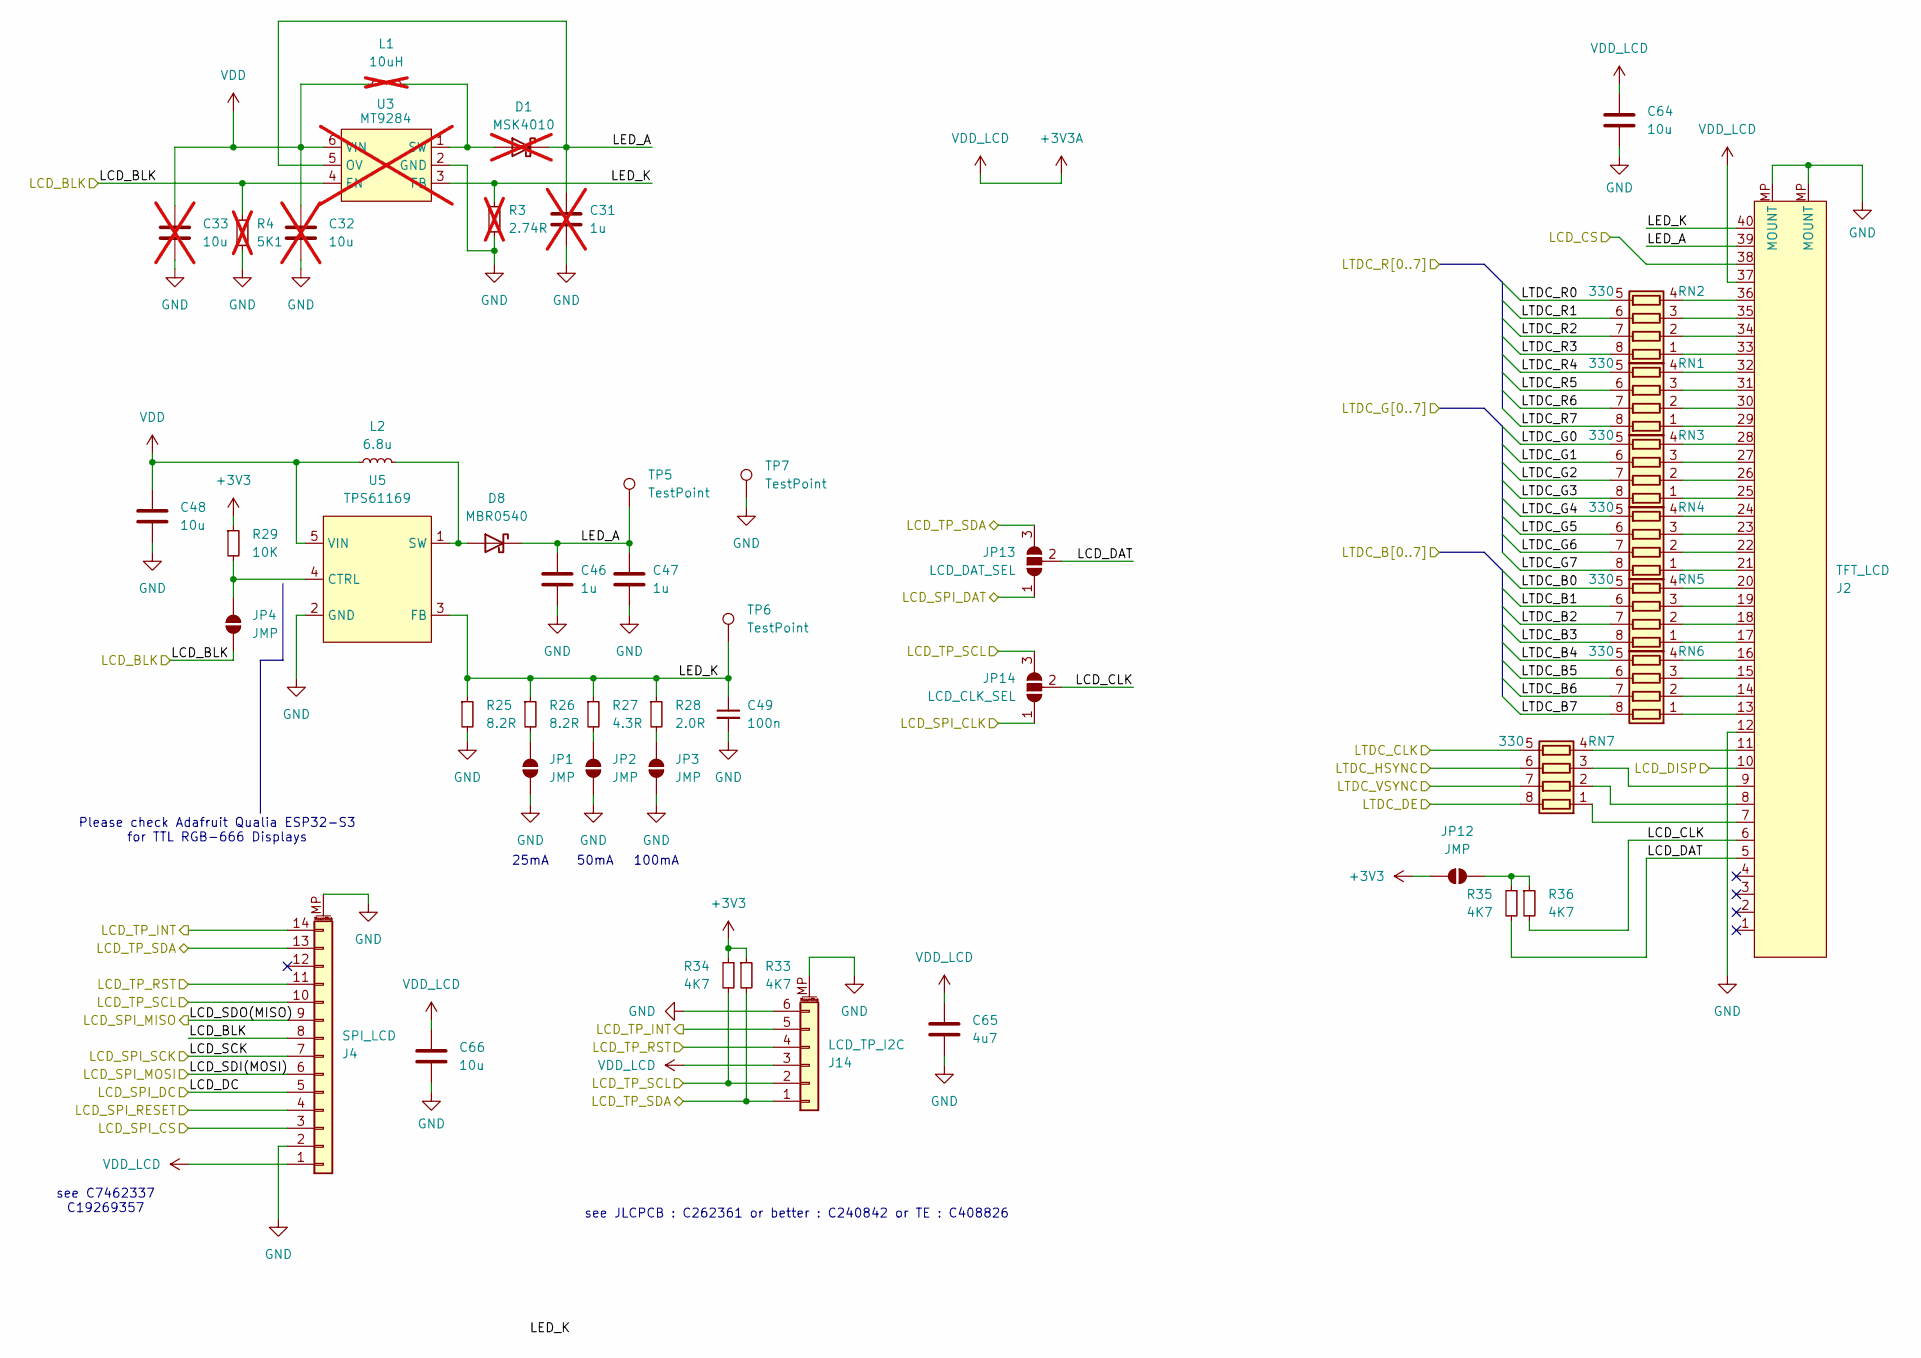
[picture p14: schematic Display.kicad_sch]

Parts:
C31: 1u; C_0603_1608Metric; JLCPCB Part # C15849; not fitted
C32, C33: 10u; C_0603_1608Metric; JLCPCB Part # C96446; not fitted
C46, C47: 1u; C_0603_1608Metric; JLCPCB Part # C15849
C48, C64, C66: 10u; C_0603_1608Metric; JLCPCB Part # C96446
C49: 100n; C_0402_1005Metric; JLCPCB Part # C307331
C65: 4u7; C_0603_1608Metric; JLCPCB Part # C19666
D1: MSK4010; D_SOD-523; JLCPCB Part # C345958; not fitted
D8: MBR0540; D_SOD-123; JLCPCB Part # C21353
J2: TFT_LCD; Omron-XF2M-4015-1A-R100-0-0-0; JLCPCB Part # C225713
J4: SPI_LCD; FPC-14P-1mm-XUNPU; JLCPCB Part # C19269357
J14: LCD_TP_I2C; TE_84952-6_1x06-1MP_P1.0mm_Horizontal; JLCPCB Part # C408826
JP1, JP2, JP3, JP4, JP12: JMP; SolderJumper-2_P1.3mm_Open_RoundedPad1.0x1.5mm
JP13: LCD_DAT_SEL; SolderJumper-3_P1.3mm_Open_RoundedPad1.0x1.5mm_NumberLabels
JP14: LCD_CLK_SEL; SolderJumper-3_P1.3mm_Open_RoundedPad1.0x1.5mm_NumberLabels
L1: 10uH; L_1210_3225Metric; JLCPCB Part # C189932; not fitted
L2: 6.8u; L_1210_3225Metric; JLCPCB Part # C844992
R3: 2.74R; R_0402_1005Metric; JLCPCB Part # C166483; not fitted
R4: 5K1; R_0402_1005Metric; JLCPCB Part # C25905; not fitted
R25, R26: 8.2R; R_0402_1005Metric; JLCPCB Part # C514788
R27: 4.3R; R_0402_1005Metric; JLCPCB Part # C166641
R28: 2.0R; R_0402_1005Metric; JLCPCB Part # C203084
R29: 10K; R_0402_1005Metric; JLCPCB Part # C25744
R33, R34, R35, R36: 4K7; R_0402_1005Metric; JLCPCB Part # C203084
RN1, RN2, RN3, RN4, RN5, RN6, RN7: 330; R_Array_Convex_4x0603; JLCPCB Part # C12018
TP5, TP6, TP7: TestPoint; TestPoint_Pad_D1.5mm
U3: MT9284; SOT-23-6; JLCPCB Part # C181780; not fitted
U5: TPS61169; SOT-353_SC-70-5; JLCPCB Part # C71045

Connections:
+3V3: JP12.2 (B), R29.1, R33.1, R34.1; also elsewhere on the board
+3V3A: C64.1, C65.1, C66.1, J2.37, J4.1, J14.3; also elsewhere on the board
/LCD/LCD_BLK: J4.8, JP4.1 (A), R4.1, U3.4 (EN); also elsewhere on the board
/LCD/LCD_CLK: J2.6, JP14.2 (C), R36.2
/LCD/LCD_CS: J2.38; also elsewhere on the board
/LCD/LCD_DAT: J2.5, JP13.2 (C), R35.2
/LCD/LCD_DC: J4.5; also elsewhere on the board
/LCD/LCD_DISP: J2.10; also elsewhere on the board
/LCD/LCD_SCK: J4.7; also elsewhere on the board
/LCD/LCD_SDI(MOSI): J4.6; also elsewhere on the board
/LCD/LCD_SDO(MISO): J4.9; also elsewhere on the board
/LCD/LCD_SPI_CLK: JP14.1 (A); also elsewhere on the board
/LCD/LCD_SPI_CS: J4.3; also elsewhere on the board
/LCD/LCD_SPI_DAT: JP13.1 (A); also elsewhere on the board
/LCD/LCD_SPI_RESET: J4.4; also elsewhere on the board
/LCD/LCD_TP_INT: J4.14, J14.5; also elsewhere on the board
/LCD/LCD_TP_RST: J4.11, J14.4; also elsewhere on the board
/LCD/LCD_TP_SCL: J4.10, J14.2, JP14.3 (B), R34.2; also elsewhere on the board
/LCD/LCD_TP_SDA: J4.13, J14.1, JP13.3 (B), R33.2; also elsewhere on the board
/LCD/LED_A: C31.1, C46.1, C47.1, D1.1 (K), D8.1 (K), J2.39, TP5.1, U3.5 (OV)
/LCD/LED_K: C49.1, J2.40, R3.1, R25.1, R26.1, R27.1, R28.1, TP6.1, U3.3 (FB), U5.3 (FB)
/LCD/LTDC_B0: RN5.5 (R4.2); also elsewhere on the board
/LCD/LTDC_B1: RN5.6 (R3.2); also elsewhere on the board
/LCD/LTDC_B2: RN5.7 (R2.2); also elsewhere on the board
/LCD/LTDC_B3: RN5.8 (R1.2); also elsewhere on the board
/LCD/LTDC_B4: RN6.5 (R4.2); also elsewhere on the board
/LCD/LTDC_B5: RN6.6 (R3.2); also elsewhere on the board
/LCD/LTDC_B6: RN6.7 (R2.2); also elsewhere on the board
/LCD/LTDC_B7: RN6.8 (R1.2); also elsewhere on the board
/LCD/LTDC_CLK: RN7.5 (R4.2); also elsewhere on the board
/LCD/LTDC_DE: RN7.8 (R1.2); also elsewhere on the board
/LCD/LTDC_G0: RN3.5 (R4.2); also elsewhere on the board
/LCD/LTDC_G1: RN3.6 (R3.2); also elsewhere on the board
/LCD/LTDC_G2: RN3.7 (R2.2); also elsewhere on the board
/LCD/LTDC_G3: RN3.8 (R1.2); also elsewhere on the board
/LCD/LTDC_G4: RN4.5 (R4.2); also elsewhere on the board
/LCD/LTDC_G5: RN4.6 (R3.2); also elsewhere on the board
/LCD/LTDC_G6: RN4.7 (R2.2); also elsewhere on the board
/LCD/LTDC_G7: RN4.8 (R1.2); also elsewhere on the board
/LCD/LTDC_HSYNC: RN7.6 (R3.2); also elsewhere on the board
/LCD/LTDC_R0: RN2.5 (R4.2); also elsewhere on the board
/LCD/LTDC_R1: RN2.6 (R3.2); also elsewhere on the board
/LCD/LTDC_R2: RN2.7 (R2.2); also elsewhere on the board
/LCD/LTDC_R3: RN2.8 (R1.2); also elsewhere on the board
/LCD/LTDC_R4: RN1.5 (R4.2); also elsewhere on the board
/LCD/LTDC_R5: RN1.6 (R3.2); also elsewhere on the board
/LCD/LTDC_R6: RN1.7 (R2.2); also elsewhere on the board
/LCD/LTDC_R7: RN1.8 (R1.2); also elsewhere on the board
/LCD/LTDC_VSYNC: RN7.7 (R2.2); also elsewhere on the board
GND: C31.2, C32.2, C33.2, C46.2, C47.2, C48.2, C49.2, C64.2, C65.2, C66.2, J2.12, J2.MP (MOUNT), J4.2, J4.MP (MountPin), J14.6, J14.MP (MountPin), JP1.1 (A), JP2.1 (A), JP3.1 (A), R3.2, R4.2, R25.2, TP7.1, U3.2 (GND), U5.2 (GND); also elsewhere on the board
unnamed: D1.2 (A), L1.2, U3.1 (SW)
unnamed: D8.2 (A), L2.2, U5.1 (SW)
unnamed: JP1.2 (B), R26.2
unnamed: JP2.2 (B), R27.2
unnamed: JP3.2 (B), R28.2
unnamed: JP4.2 (B), R29.2, U5.4 (CTRL)
unnamed: JP12.1 (A), R35.1, R36.1
unnamed: J2.29, RN1.1 (R1.1)
unnamed: J2.30, RN1.2 (R2.1)
unnamed: J2.31, RN1.3 (R3.1)
unnamed: J2.32, RN1.4 (R4.1)
unnamed: J2.33, RN2.1 (R1.1)
unnamed: J2.34, RN2.2 (R2.1)
unnamed: J2.35, RN2.3 (R3.1)
unnamed: J2.36, RN2.4 (R4.1)
unnamed: J2.25, RN3.1 (R1.1)
unnamed: J2.26, RN3.2 (R2.1)
unnamed: J2.27, RN3.3 (R3.1)
unnamed: J2.28, RN3.4 (R4.1)
unnamed: J2.21, RN4.1 (R1.1)
unnamed: J2.22, RN4.2 (R2.1)
unnamed: J2.23, RN4.3 (R3.1)
unnamed: J2.24, RN4.4 (R4.1)
unnamed: J2.17, RN5.1 (R1.1)
unnamed: J2.18, RN5.2 (R2.1)
unnamed: J2.19, RN5.3 (R3.1)
unnamed: J2.20, RN5.4 (R4.1)
unnamed: J2.13, RN6.1 (R1.1)
unnamed: J2.14, RN6.2 (R2.1)
unnamed: J2.15, RN6.3 (R3.1)
unnamed: J2.16, RN6.4 (R4.1)
unnamed: J2.7, RN7.1 (R1.1)
unnamed: J2.8, RN7.2 (R2.1)
unnamed: J2.9, RN7.3 (R3.1)
unnamed: J2.11, RN7.4 (R4.1)
VDD: C32.1, C33.1, C48.1, L1.1, L2.1, U3.6 (VIN), U5.5 (VIN); also elsewhere on the board

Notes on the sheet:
100mA
see C7462337 C19269357
see JLCPCB : C262361 or better : C240842 or TE : C408826
50mA
25mA
Please check Adafruit Qualia ESP32-S3 for TTL RGB-666 Displays

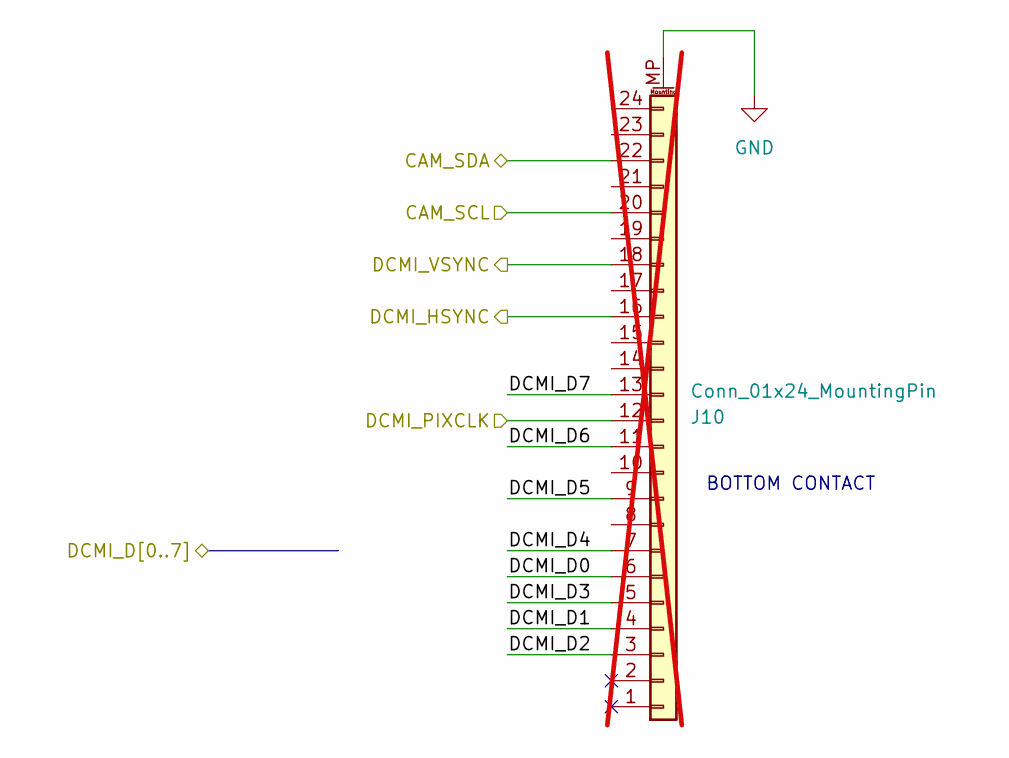
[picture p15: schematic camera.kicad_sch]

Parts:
J10: Conn_01x24_MountingPin; Jushuo_AFC07-S24FCA-00_1x24-1MP_P0.50_Horizontal; JLCPCB Part # C262567; not fitted

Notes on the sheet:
BOTTOM CONTACT

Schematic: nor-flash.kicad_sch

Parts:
C21, C22: 100n; C_0402_1005Metric; JLCPCB Part # C307331
JP8: FLASH_CONFIG; SolderJumper-3_P1.3mm_Open_RoundedPad1.0x1.5mm_NumberLabels
JP9: FLASH_EN; SolderJumper-2_P1.3mm_Open_RoundedPad1.0x1.5mm
R1, R2: 10K; R_0402_1005Metric; JLCPCB Part # C25744
U1, U4: MT25Q; WSON-8-1EP_8x6mm_P1.27mm_EP3.4x4.3mm; JLCPCB Part # C2061007

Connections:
+3V3: C21.1, JP9.2 (B), R1.1, R2.1, U1.8 (VCC); also elsewhere on the board
/MCU/QUADSPI_BK1_IO0: U1.5 (DI(IO0)); also elsewhere on the board
/MCU/QUADSPI_BK1_IO1: U1.2 (DO(IO1)); also elsewhere on the board
/MCU/QUADSPI_BK1_IO2: U1.3 (IO2); also elsewhere on the board
/MCU/QUADSPI_BK1_IO3: U1.7 (IO3); also elsewhere on the board
/MCU/QUADSPI_BK1_NCS: JP8.3 (B), R1.2, U1.1 (~CS); also elsewhere on the board
/MCU/QUADSPI_BK2_IO0: U4.5 (DI(IO0)); also elsewhere on the board
/MCU/QUADSPI_BK2_IO1: U4.2 (DO(IO1)); also elsewhere on the board
/MCU/QUADSPI_BK2_IO2: U4.3 (IO2); also elsewhere on the board
/MCU/QUADSPI_BK2_IO3: U4.7 (IO3); also elsewhere on the board
/MCU/QUADSPI_BK2_NCS: JP8.1 (A); also elsewhere on the board
/MCU/QUADSPI_CLK: U1.6 (CLK), U4.6 (CLK); also elsewhere on the board
GND: C21.2, C22.2, U1.4 (GND), U1.9 (EP), U4.4 (GND), U4.9 (EP); also elsewhere on the board
unnamed: JP8.2 (C), R2.2, U4.1 (~CS)
unnamed: C22.1, JP9.1 (A), U4.8 (VCC)

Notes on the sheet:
NOR FLASH

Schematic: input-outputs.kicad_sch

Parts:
C67: 10u; C_0603_1608Metric; JLCPCB Part # C96446
D9: ESDA14V2L; SOT-23; JLCPCB Part # C343996
D10: NSR0320MW2T1G; D_SOD-323; JLCPCB Part # C48192
J5: I2C-STEMMA-QT; JST_SM04B-SRSS-TB_LF__SN_; JLCPCB Part # C160404
J7: swd; PinHeader_2x07_P1.27mm_Vertical_SMD; JLCPCB Part # C2881912
J9: UART; Hirose_DF13C_CL535-0404-8-51_1x04-1MP_P1.25mm_Vertical; JLCPCB Part # C7430470
NT1: NetTie_2; NetTie-2_SMD_Pad0.5mm

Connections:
+3V3: C67.1, J5.3, J7.3; also elsewhere on the board
+5V: J9.1, NT1.2; also elsewhere on the board
/IO/DBG_RX: J7.13; also elsewhere on the board
/IO/DBG_SWCLK: J7.6; also elsewhere on the board
/IO/DBG_SWDIO: J7.4; also elsewhere on the board
/IO/DBG_SWO: J7.8; also elsewhere on the board
/IO/DBG_TX: J7.14; also elsewhere on the board
/IO/STEMMA_SCL: J5.1; also elsewhere on the board
/IO/STEMMA_SDA: J5.2; also elsewhere on the board
/IO/USART6_RX: D9.1 (K), J9.2; also elsewhere on the board
/IO/USART6_TX: D9.2 (K), J9.3; also elsewhere on the board
/MCU/NRST: J7.12; also elsewhere on the board
GND: C67.2, D9.3 (A), J5.4, J5.S1 (SHIELD), J5.S2 (SHIELD), J7.2, J7.5, J7.7, J9.4, J9.MP (MountPin); also elsewhere on the board
unnamed: D10.2 (A), J7.1
VBUS: NT1.1; also elsewhere on the board
VDD: D10.1 (K); also elsewhere on the board

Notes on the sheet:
TO MCU TX
TO MCU RX

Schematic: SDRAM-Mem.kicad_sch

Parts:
C1, C2, C3, C29, C36, C37, C38: 100n; C_0402_1005Metric; JLCPCB Part # C307331
U9: MT48LC16M16A2P; TSOP-II-54_22.2x10.16mm_P0.8mm; JLCPCB Part # C412833

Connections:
+3V3: C1.1, C2.1, C3.1, C29.1, C36.1, C37.1, C38.1, U9.1 (VDD), U9.3 (VDDQ), U9.9 (VDDQ), U9.14 (VDD), U9.27 (VDD), U9.43 (VDDQ), U9.49 (VDDQ); also elsewhere on the board
/MCU/SDRAM_ADD0: U9.23 (A0); also elsewhere on the board
/MCU/SDRAM_ADD1: U9.24 (A1); also elsewhere on the board
/MCU/SDRAM_ADD2: U9.25 (A2); also elsewhere on the board
/MCU/SDRAM_ADD3: U9.26 (A3); also elsewhere on the board
/MCU/SDRAM_ADD4: U9.29 (A4); also elsewhere on the board
/MCU/SDRAM_ADD5: U9.30 (A5); also elsewhere on the board
/MCU/SDRAM_ADD6: U9.31 (A6); also elsewhere on the board
/MCU/SDRAM_ADD7: U9.32 (A7); also elsewhere on the board
/MCU/SDRAM_ADD8: U9.33 (A8); also elsewhere on the board
/MCU/SDRAM_ADD9: U9.34 (A9); also elsewhere on the board
/MCU/SDRAM_ADD10: U9.22 (A10); also elsewhere on the board
/MCU/SDRAM_ADD11: U9.35 (A11); also elsewhere on the board
/MCU/SDRAM_ADD12: U9.36 (A12); also elsewhere on the board
/MCU/SDRAM_DQ0: U9.2 (DQ0); also elsewhere on the board
/MCU/SDRAM_DQ1: U9.4 (DQ1); also elsewhere on the board
/MCU/SDRAM_DQ2: U9.5 (DQ2); also elsewhere on the board
/MCU/SDRAM_DQ3: U9.7 (DQ3); also elsewhere on the board
/MCU/SDRAM_DQ4: U9.8 (DQ4); also elsewhere on the board
/MCU/SDRAM_DQ5: U9.10 (DQ5); also elsewhere on the board
/MCU/SDRAM_DQ6: U9.11 (DQ6); also elsewhere on the board
/MCU/SDRAM_DQ7: U9.13 (DQ7); also elsewhere on the board
/MCU/SDRAM_DQ8: U9.42 (DQ8); also elsewhere on the board
/MCU/SDRAM_DQ9: U9.44 (DQ9); also elsewhere on the board
/MCU/SDRAM_DQ10: U9.45 (DQ10); also elsewhere on the board
/MCU/SDRAM_DQ11: U9.47 (DQ11); also elsewhere on the board
/MCU/SDRAM_DQ12: U9.48 (DQ12); also elsewhere on the board
/MCU/SDRAM_DQ13: U9.50 (DQ13); also elsewhere on the board
/MCU/SDRAM_DQ14: U9.51 (DQ14); also elsewhere on the board
/MCU/SDRAM_DQ15: U9.53 (DQ15); also elsewhere on the board
/MEMORY SDRAM/SDRAM_BA0: U9.20 (BA0); also elsewhere on the board
/MEMORY SDRAM/SDRAM_BA1: U9.21 (BA1); also elsewhere on the board
/MEMORY SDRAM/SDRAM_CKE: U9.37 (CKE); also elsewhere on the board
/MEMORY SDRAM/SDRAM_CLK: U9.38 (CLK); also elsewhere on the board
/MEMORY SDRAM/SDRAM_LDQM: U9.15 (DQML); also elsewhere on the board
/MEMORY SDRAM/SDRAM_UDQM: U9.39 (DQMH); also elsewhere on the board
/MEMORY SDRAM/~SDRAM_CAS: U9.17 (~CAS); also elsewhere on the board
/MEMORY SDRAM/~SDRAM_CS: U9.19 (~CS); also elsewhere on the board
/MEMORY SDRAM/~SDRAM_RAS: U9.18 (~RAS); also elsewhere on the board
/MEMORY SDRAM/~SDRAM_WE: U9.16 (~WE); also elsewhere on the board
GND: C1.2, C2.2, C3.2, C29.2, C36.2, C37.2, C38.2, U9.6 (VSSQ), U9.12 (VSSQ), U9.28 (VSS), U9.41 (VSS), U9.46 (VSSQ), U9.52 (VSSQ), U9.54 (VSS); also elsewhere on the board

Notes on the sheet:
or IS42S16160J-7TL
C412833

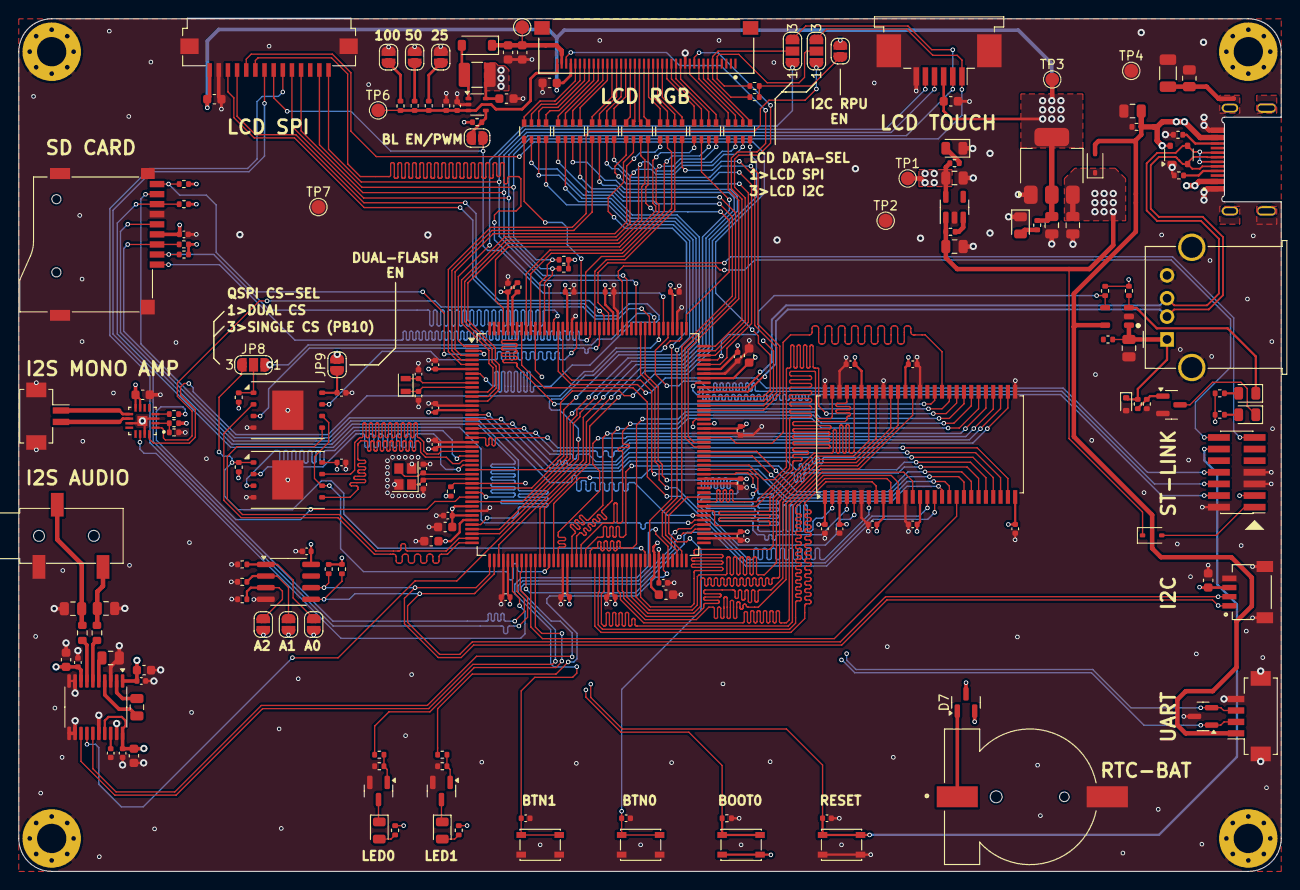
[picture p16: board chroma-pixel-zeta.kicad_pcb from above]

Board: 4 copper layers, 138.0 x 93.2 mm, 190 parts (0 on the bottom side), 213 nets.

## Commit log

2024-07-09 Change MCU to STM32H743IIT6
    [Display.kicad_sch, MAX98357.kicad_sch, SDRAM.kicad_sch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]
2024-07-09 Cleaning schematic, added more independently schematics
    [Display.kicad_sch, MAX98357.kicad_sch, SDRAM-Mem.kicad_sch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]
2024-07-10 Layout SDRAM
    [Display.kicad_sch, MAX98357.kicad_sch, SDRAM-Mem.kicad_sch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]
2024-07-10 relayout SDRAM
    [Display.kicad_sch, MAX98357.kicad_sch, SDRAM-Mem.kicad_sch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]
2024-07-11 Finished SDRAM, QSPI Flash, Planning to move to 5 inch orient display dimension
    [Display.kicad_sch, MAX98357.kicad_sch, STM32H743IIK6.kicad_sch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]
2024-07-11 Move to 5 inch dimension
    [chroma-pixel-zeta.kicad_pcb]
2024-07-11 finished layout backlight driver
    [chroma-pixel-zeta.kicad_pcb]
2024-07-12 Changes: USB C to midmount, CR1220 socket, flip MCU to shorten the LCD traces
    [Display.kicad_sch, STM32H743IIK6.kicad_sch, chroma-pixel-zeta.kicad_pcb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]
2024-07-14 Finished SDRAM, LTDC, QSPI, SDMMC, still an error on LTDC B channel
    [Display.kicad_sch, STM32H743IIK6.kicad_sch, chroma-pixel-zeta.kicad_pcb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]
2024-07-14 Finished SDRAM, QSPI, SDMMC, LTDC, TP, EEPROM, USB, debug (need to verify on UART)
    [Display.kicad_sch, MAX98357.kicad_sch, SDRAM-Mem.kicad_sch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]
2024-07-16 via changed to 0.3/0.5
    [chroma-pixel-zeta.kicad_pcb]
2024-07-16 not yet
    [Display.kicad_sch, MAX98357.kicad_sch, SDRAM-Mem.kicad_sch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]
2024-07-17 Button, LED, i2s audio, LCD & SD ctrl left
    [Display.kicad_sch, MAX98357.kicad_sch, SDRAM-Mem.kicad_sch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]
2024-07-17 Almost finished
    [Display.kicad_sch, MAX98357.kicad_sch, SDRAM-Mem.kicad_sch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]
2024-07-18 Still on progress...
    [Display.kicad_sch, MAX98357.kicad_sch, SDRAM-Mem.kicad_sch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]
2024-07-18 Removing Camera, create alternative footprint for SPI LCD conn
    [Display.kicad_sch, MAX98357.kicad_sch, SDRAM-Mem.kicad_sch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]
2024-07-19 First release
    [Display.kicad_sch, MAX98357.kicad_sch, SDRAM-Mem.kicad_sch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]
